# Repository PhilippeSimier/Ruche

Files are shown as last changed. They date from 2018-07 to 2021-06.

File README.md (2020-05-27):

# The connected Beehive 
D’une installation facile et rapide, le système se positionne sous n’importe quelle ruche et délivre en temps réel un suivi précis des grandeurs mesurées.  Si la connexion réseau est présente, les grandeurs mesurées sont stokées sur la plate forme Thing Speak,  dans le cas contraire, les mesures sont enregistrées localement dans une base de données. Les mesures peuvent être consultées via des vues graphiques sur un site WEB.

**ThingSpeak** est une API et une application open source pour l'« Internet des objets », permettant de stocker et de collecter les données des objets connectés en passant par le protocole HTTP via Internet. Les données collectées peuvent être analysées avec des programmes MATLAB. On peut ainsi tracer des diagrammes de corrélation, effectuer des statistiques (calcul de moyenne mini maxi etc...

En cas de besoin d’intervention, des alertes sont transmises par  sms sur  smartphone. Ce service est assurée par une API sur la Gateway.

## Câblage d'une balance connectée
Réaliser le câblage suivant sur la carte **snir-hat**
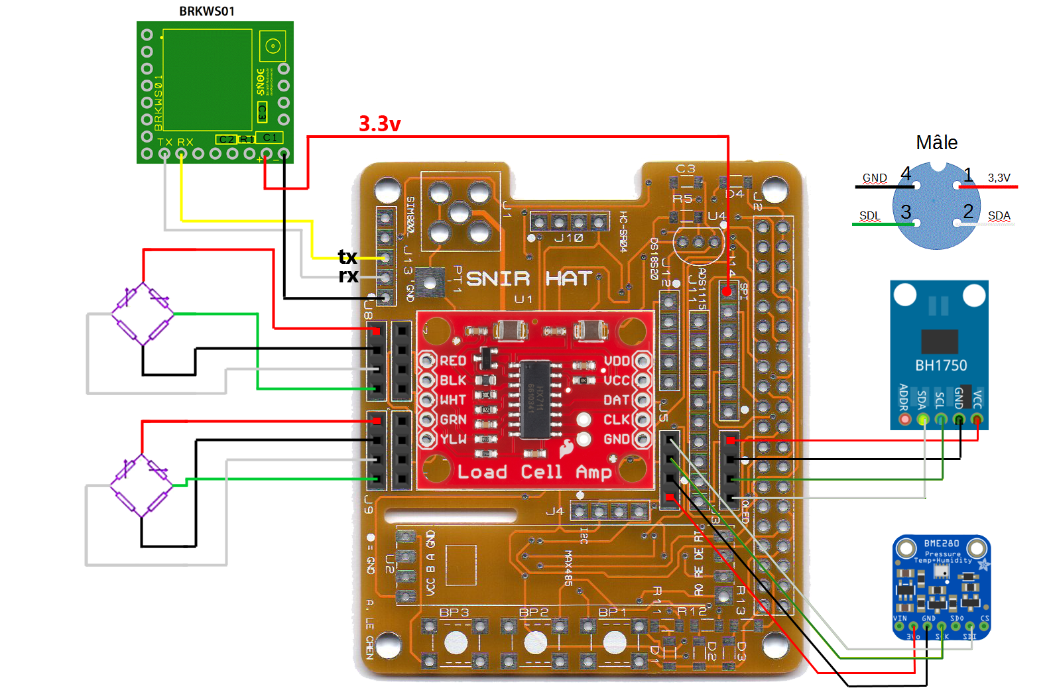
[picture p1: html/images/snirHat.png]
schema cablage HX711

 
## Prérequis Installation

Sous **raspbian lite Buster** Les paquets suivants doivent être installés 

 1. git
 2. apache2
 2. mariadb
 3. php
 4. php7.0-curl
 4. phpmyadmin
 5. libcurl4-openssl-dev
 6. libmysqlcppconn-dev

Configuration de Apache

 1. Activer le module cgi
 2. Activer le module rewrite
 2. ajouter www-data au groupe video et i2c
 
Vous pouvez utiliser le script shell **RaspbianOSsetup.sh** pour installer les packages requis et configurer Apache. 
```bash
~ $ sudo su
/home/pi# apt install git
/home/pi# git clone https://github.com/PhilippeSimier/Ruche.git
/home/pi# cd Ruche/
/home/pi/Ruche#  ./Raspbian_OS_Setup/RaspbianOSsetup.sh
```
## Création de la base de données data

 - création d'une base **data**
 - création d'un utilisateur **ruche** avec mdp **toto**
 - création des tables users, things, channels et feeds
 
Vous pouvez  en tant que **root** utiliser le script shell **mysql_data_setup** pour installer la base de données  et créer l'utilisateur 'ruche' requis.

```bash
/home/pi/Ruche# ./Raspbian_OS_Setup/mysql_Data_setup
```
 
## Compilation & installation 

 **make  all** 
```bash
~/Ruche $ cd Capteurs
~/Ruche/Capteurs $ make all
~/Ruche/Capteurs $ make install
~/Ruche/Capteurs $ make clean
```
Installation des exécutables

**make install**

Installation des fichiers de configurations

**make config**

## Thing Speak

Pour pouvoir télécharger les données sur ThingSpeak à des fins d'analyse et de traitement, vous devez créer un compte.

Une fois le compte créé, vous devez créer un nouveau canal en lui donnant un nom.
Les champs reflètent les données que vous allez télécharger.  
Vous devez définir les champs  comme sur la figure ci-dessous. 
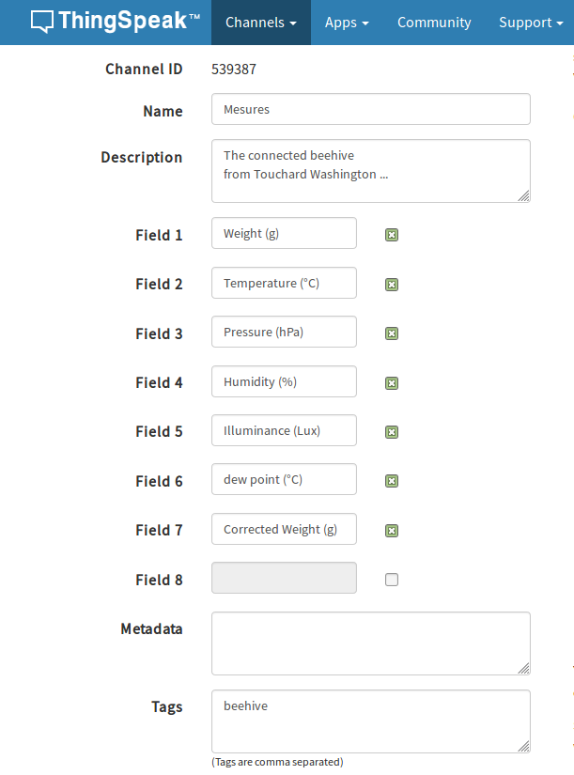
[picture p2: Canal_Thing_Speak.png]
Canaux Thing Speak


À l'issue de cette opération, cliquez sur Enregistrer le canal.  Vous êtes maintenant prêt à télécharger les données de la ruche vers son canal correspondant.

Recherchez la clé API correspondant à votre canal (Write API Key).
À chaque canal correspondra une clé API unique, destinée à garantir le téléchargement des données au bon emplacement.

Veuillez à mémoriser la clé API **Write API Key** . Vous l'utiliserez comme argument des tâches thingSpeak qui seront exécutées à interval régulier par le processus cron.

## Configuration **crontab**
ajouter les tâches planifiées suivantes :

 - Exécution de **bddLog** toutes les 30 minutes;
 - Exécution de **thingSpeak** toutes les 30 minutes;
 - Exécution de **synchronisation** toute les 4 heures lorsque l'aiguille des minutes est sur 5. 

```bash
/home/pi/Ruche# crontab -e

*/30 * * * * /opt/Ruche/bin/bddLog >> /var/log/Ruche/activity.log 2>&1
*/30 * * * * /opt/Ruche/bin/thingSpeakGET XXXXXXXXXXXXX | /opt/Ruche/bin/envoyerURL >> /var/log/Ruche/activity.log 2>&1
*/30 * * * * /opt/Ruche/bin/weather XXXXXXXXXXXX | /opt/Ruche/bin/envoyerURL >> /var/log/Ruche/activity.log 2>&1

```
## Configuration et Etalonnage de la **balance**

La balance doit être étalonnée. Cette procédure consiste à prendre un poids connu (p. ex. 5 kg) et d'établir la relation pour que la valeur affichée à l'écran corresponde à la valeur connue.
Le programme **etalonnage** permet de déterminer les paramètres de cette relation et de les enregistrer dans le fichier **configuration.ini**.
Pour ce faire, en mode console lancer le programme **etalonnage**
```bash
~/Ruche $ cd Capteurs/
~/Ruche/Capteurs $ ./etalonnage
Quelle est l'unité de mesure ? (g kg lb)
kg
Quelle est la précision d'affichage : 1 ou 2 chiffres après la virgule
2
Donnez le gain souhaité : 128 ou 64 ? 
64

```
Répondez aux différentes questions, le programme va ensuite lancer la procédure de tarage, puis va vous demandez de placer un poids étalon sur le plateau de la balance.  Vous devez donner sa valeur. Le programme continue alors sa procédure.

Sans retirer le poids étalon lancer le programme testBalance
```bash
~/Ruche/Capteurs $ ./testBalance
* 15.00
```
Vous devriez voir s'afficher sur l'écran la valeur du poids étalon.
La configuration de la balance est terminée.

## Test des capteurs BME280 et BH1750
Le test de fonctionnement du capteur BME280 peut être effectué en exécutant le programme : **testBME280**
```bash
~/Ruche/Capteurs $ ./testBME280 
Capteur BME 280 présent sur le bus I2C
 Température (C)  : 28.0 °C
 Température (F)  : 82.5 °F
 Pression         : 1018.9 hPa
 Humidité         : 42.3 %
 Pression P0      : 1023.7 hPa
 Point de rosée   : 14.0 °C

```
Le test de fonctionnement du capteur BH1750 peut être effectué en exécutant le programme : **testBH1750**

```bash
~/Ruche/Capteurs $ ./testBH1750
Capteur d'éclairement
Eclairement : 222.9 lx
Eclairement : 222.9 lx
Eclairement : 222.9 lx
^C
```

## Site Web

Dans un navigateur web ouvrir l'url suivante: 
http://adresse_IP_du_raspberry

--------

## Changelog

 **04/08/2018 :** Ajout du README . 
 **10/09/2018 :** Ajout du  script shell RaspbianOSsetup.sh
 
> **Notes :**

> - Licence : **licence publique générale** 
> - Auteur **Philippe SIMIER Lycée Touchard Le Mans**
>  
<!-- TOOLBOX 

Génération des badges : https://shields.io/
Génération de ce fichier : https://stackedit.io/editor#

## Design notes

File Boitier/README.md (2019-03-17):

# Boitier Ruche connectée

## Conception boîtier 3D

Le boitier se place sous la ruche. Il contient la batterie, le chargeur solaire, le raspberry pi. Le couvercle est le plateau de la balance. 

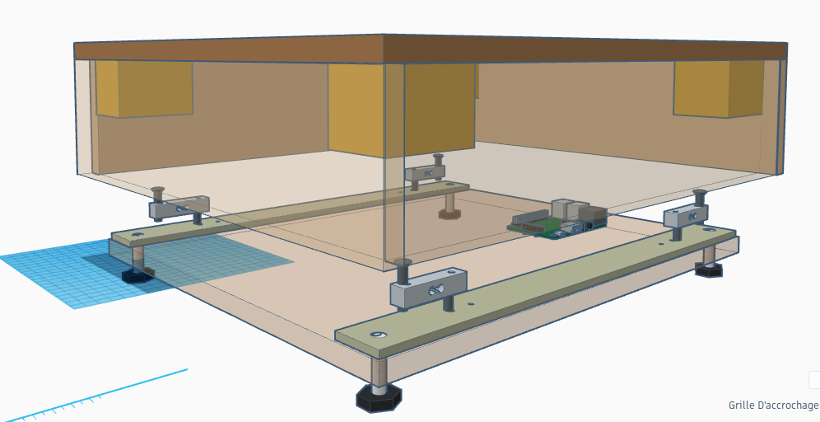
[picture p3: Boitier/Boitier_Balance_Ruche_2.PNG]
boitier


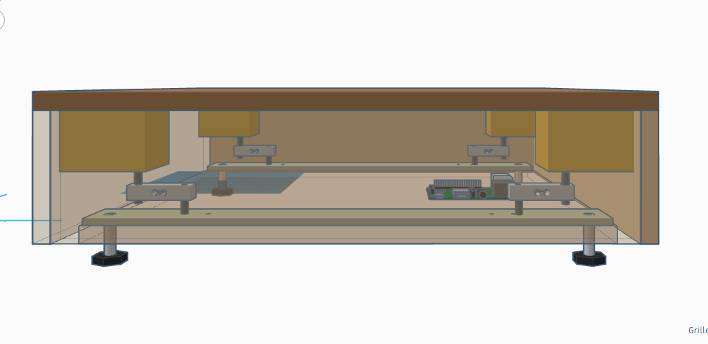
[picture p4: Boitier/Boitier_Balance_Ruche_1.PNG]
boitier


[Modèle 3D](https://www.tinkercad.com/things/l4oGmu31n0B-boitier-balance-ruche)

## Changelog

 **04/08/2018 :** Ajout du README . 
 **10/09/2018 :** Ajout du  script shell RaspbianOSsetup.sh
 
> **Notes :**

> - Licence : **licence publique générale** 
> - Auteur **Philippe SIMIER Lycée Touchard Le Mans**
>  
<!-- TOOLBOX 

Génération des badges : https://shields.io/
Génération de ce fichier : https://stackedit.io/editor#

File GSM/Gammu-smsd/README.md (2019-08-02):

# Gammu-smsd

**gammu-smsd** est un programme daemon qui se charge de recevoir et d'envoyer les SMS. Pour ce faire il analyse périodiquement le modem GSM pour lire les SMS reçus et les stocker dans un répertoire défini. Il envoie les SMS placés dans le répertoire des SMS à envoyer.

***Attention*** vous ne pouvez pas exécuter Gammu et Gammu-SMSD en même temps sur le même modem GSM, cependant vous pouvez contourner cette limitation en suspendant temporairement SMSD en utilisant les signaux SIGUSR1 et SIGUSR2.

 - **SIGUSR1** Suspend  SMSD, en fermant la connexion au modem GSM
 - **SIGUSR2** Reprend  SMSD (après la suspension précédente).

## Installation
```bash
pi@raspberrypi3:~ $ sudo apt-get install gammu-smsd
pi@raspberrypi3:~ $ gammu-smsd -v
Gammu-smsd version 1.33.0

```
## Configuration de Gammu-smsd

gammu-smsd lit la configuration à partir d'un fichier de configuration. Son emplacement peut être spécifié sur la ligne de commande (option -c), sinon le fichier par défaut **/etc/gammu-smsdrc** est utilisé.

La section **[gammu]** est la configuration d'une connexion au modem GSM
la section **[smsd]** configure le démon SMS lui-même.
Le paramètre **pin**  est facultatif, mais vous devez le définir si votre carte SIM après la mise sous tension nécessite un code PIN.

Exemple de fichier de configuration :
```
# Configuration file for Gammu SMS Daemon

[gammu]

port = /dev/ttyUSB0
connection = at
GammuLoc = fr_FR.UTF8
gammucoding = utf8

[smsd]
service = files
logfile = syslog
# Increase for debugging information
debuglevel = 0
RunOnReceive = /home/pi/Ruche/SMSDreceive.sh
pin = 0000

# Paths where messages are stored
inboxpath = /var/spool/gammu/inbox/
outboxpath = /var/spool/gammu/outbox/
sentsmspath = /var/spool/gammu/sent/
errorsmspath = /var/spool/gammu/error/
```
Le répertoire **/var/spool/gammu/inbox/** contient les SMS reçus. Chaque SMS reçu est mémorisé dans un fichier texte. Le nom du fichier est composé de la date de réception suivi du numéro de téléphone expéditeur.  Exemple : **IN20180929_220922_00_+33689744236_00.txt**

Le répertoire  /var/spool/gammu/sent/ contient les SMS émis. Chaque SMS émis est mémorisé dans un fichier texte.  Exemple :
**OUTC20180930_181847_00_0689744235_sms0.smsbackup**

## Démarrer le démon smsd

```bash
pi@raspberrypi3:/etc $ sudo service gammu-smsd start
```

## Stoper le démon smsd
```bash
pi@raspberrypi3:/etc $ sudo service gammu-smsd stop
```

## Redémarrer le démon smsd
```bash
pi@raspberrypi3:/etc $ sudo service gammu-smsd stop restart 
```

## Vérifier l'état du démon gammu_smsd
```bash
pi@raspberrypi3:~ $ sudo service gammu-smsd status
● gammu-smsd.service - LSB: Gammu SMS daemon
   Loaded: loaded (/etc/init.d/gammu-smsd)
   Active: active (exited) since dim. 2018-09-30 17:50:35 CEST; 8min ago

sept. 30 17:50:35 raspberrypi3 gammu-smsd[29650]: gammu-smsd not yet configured, please...).
sept. 30 17:50:35 raspberrypi3 systemd[1]: Started LSB: Gammu SMS daemon.
Hint: Some lines were ellipsized, use -l to show in full.

```

## Envoyer un SMS 

**gammu-smsd-inject** est un programme qui **met en file d'attente le message** , qui sera ensuite envoyé par le démon à l'aide du modem GSM connecté.

Injecter un **message texte** jusqu'à 160 caractères standard:
```bash
root@raspberrypi3:/# gammu-smsd-inject TEXT 0689744236 -text "Nous sommes le `date`"
gammu-smsd-inject[3314]: Created outbox message OUTC20180930_193115_00_0689744236_sms0.smsbackup
Written message with ID /var/spool/gammu/outbox/OUTC20180930_193115_00_0689744236_sms0.smsbackup

```
Injecter un **message texte Unicode**: 
```bash
root@raspberrypi3:/home/pi# gammu-smsd-inject TEXT 0689744236 -unicode -text "Zkouška sirén été Anaïs"
```

Injecter le contenu d'un **fichier text** :
Le contenu d'un fichier texte peut être envoyé sur l'entrée standard de gammu-smsd-inject. 
```bash
root@raspberrypi3:/home/pi/# cat textSMS | gammu-smsd-inject TEXT 0689744235 -unicode -len 400
```

## Recevoir un SMS et effectuer un traitement

Chaque fois que SMSD reçoit un message et le stocke dans le service backend, il peut lancer l'exécution de votre propre programme pour effectuer tout traitement sur le message reçu.

Exemple  de script: 
pi@raspberrypi3:~# nano /home/pi/Ruche/SMSDreceive.sh
```bash
#!/bin/sh
# script exécuter par le démon Gammu lors de la reception d'un SMS
# variables d'environnement
# SMS_1_CLASS
# SMS_1_NUMBER= numero tel
# SMS_1_TEXT= message
# SMS_MESSAGES = le nbre de SMS reçus
# en argument le fichier contenant le SMS

echo "---------------------------------------" >> /home/pi/Ruche/sms.log
echo "$(date) : $SMS_MESSAGES  SMS(s) recu(s)" >> /home/pi/Ruche/sms.log
echo "from : $SMS_1_NUMBER" >> /home/pi/Ruche/sms.log
echo "message : $SMS_1_TEXT" >> /home/pi/Ruche/sms.log
echo "fichier contenant le SMS : $1" >> /home/pi/Ruche/sms.log

curl --request GET  --url $SMS_1_TEXT  --header 'cache-control: no-cache' >> /home/pi/Ruche/sms.log 2>&1

exit 0

```
**Attention** Le script doit être exécutable par **gammu**,  il doit donc être exécutable, +x,  il doit avoir pour propriétaire gammu et appartenir au groupe gammu.
Ne pas oublier d'ouvrir les droits en écriture pour de répertoire Ruche.
```bash
pi@raspberrypi3:~/Ruche $ chmod +x SMSDreceive.sh
pi@raspberrypi3:~/Ruche $ sudo chown gammu SMSDreceive.sh
pi@raspberrypi3:~/Ruche $ sudo chgrp gammu SMSDreceive.sh
pi@raspberrypi3:~/Ruche $ ls -l
total 4
-rwxr-xr-x 1 gammu gammu 578 oct.   6 11:10 SMSDreceive.sh
pi@raspberrypi3:~ $ cd ..
pi@raspberrypi3:~ $ chmod 777 Ruche/

```

[Plus d'infos sur le site officiel GAMMU](https://wammu.eu/docs/manual/smsd/run.html)

## Envoyer un SMS depuis un script php

```php
<?php

    $ligne  = "gammu-smsd-inject TEXT 0612345678 -text \"Test de l'envoi SMS avec API\"";
    $output = shell_exec($ligne);
    echo "<p>output : </p><pre>" . $output . "</pr>";
?>
```
L’utilisateur apache (www-data) doit avoir accès à  /dev/ttyUSB0
Pour ce faire ajouter **www-data** au groupe **dialout**
```bash
    sudo usermod -a -G dialout www-data
```
www-data doit pouvoir exécuter gammu-smsd-inject avec les droits du propriétaire  :    *chmod +s*
```bash
root@raspberrypi3:/# cd /usr/bin/
root@raspberrypi3:/usr/bin# chmod +s gammu-smsd-inject
root@raspberrypi3:/usr/bin# chmod +s gammu-smsd-monitor

``` 

## Obtenir le niveau du signal

```bash
pi@raspberrypi3:~ $ sudo gammu-smsd-monitor -n 1 -d 1 | grep NetworkSignal
NetworkSignal: 60
```

## Obtenir l'IMEI
L'imei est un numéro permettant d'identifier de manière unique un modem GSM.
```bash
pi@PI1003:~ $ sudo gammu-smsd-monitor -n 1 -d 1 | grep IMEI
IMEI: 863071014745125

```

## Modem GSM non reconnu

Des problèmes d'émissions et de réceptions de messages ont été constatés. Après recherche et étude des logs, il s'est avéré que Gammu  avait perdu la connexion avec le modem gsm. le point de montage USB de notre modem **/dev/ttyUSB0** n'existait plus.
Le problème est que Linux fait varier ce point de montage à chaque démarrage et redémarrage même si le port USB où le modem est connecté reste inchangé. Le point de montage peut alors avoir la valeur « ttyUSB1 », « ttyUSB2 », « ttyUSB3 »....
Pour résoudre ce problème, une règle de montage des périphériques USB a été ajoutée au gestionnaire de périphérique « udev » qui est présent dans le noyau Linux dont dispose Raspbian.

Nous devons fixer le chemin afin qu'il ne change pas si d'autres périphériques sont connectés, nous choisissons **e169**. Il faut bien comprendre que nous allons ajouter un second chemin fixe en plus du premier qui lui restera dynamique, nous ne le remplaçons pas.

Première étape : Récupérez l'ID avec :  **lsusb | grep -i huawei**
 
```bash
root@raspberrypi3:/etc/udev# lsusb | grep -i huawei
Bus 001 Device 005: ID 12d1:1001 Huawei Technologies Co., Ltd. E169/E620/E800 HSDPA Modem

```
Les 2 champs qui nous intéressent sont ceux après "ID" :

 - **12d1 = idVendor**
 - **1001 = idProduct**

**Deuxième étape Fixons le chemin :**
```bash
root@raspberrypi3:~# cd /etc/udev/rules.d/
root@raspberrypi3:/etc/udev/rules.d# nano usb-modem.rules 
```
Ajouter la règle suivante dans le fichier:

la règle est faite d'un ensemble de clefs de correspondances et de clefs d'assignation, séparées par des virgules. Les clefs de correspondances sont les conditions utilisées pour identifier le périphérique sur lequel la règle agit. Quand toute la série de ces clefs de correspondance correspond bien au périphérique, alors la règle est appliquée et les actions des clefs d'assignation sont appliquées.
```
KERNEL=="ttyUSB*",ATTRS{idVendor}=="12d1",ATTRS{idProduct}=="1001",SYMLINK+="e169"
```
Cette ligne indique au système que l'appareil correspondant au idVendor et idProduct du modem monté sur n'importe quel ttyUSB devra être accessible sous le nom e169. Ainsi, le modem gsm sera toujours monté dans le répertoire /dev/e169, réglant ainsi toutes nos erreurs de déconnexions.

**Troisième étape : Vérification** 

```
root@raspberrypi3:/home/pi# ls -l /dev/e*
lrwxrwxrwx 1 root root 7 juil. 30 12:55 /dev/e169 -> ttyUSB0

```
**Quatrième étape : Modification du fichiers de configuration /etc/gammu-smsdrc** 

```
[gammu]

port = /dev/e169
connection = at
....

```

## Changelog

 **30/09/2018 :** Ajout du README .
 **30/07/2019 :** Ajout résolution de la déconnexion du modem  

> **Notes :**

> - Licence : **licence publique générale** 
> - Auteur **Philippe SIMIER Lycée Touchard Le Mans**
>  
<!-- TOOLBOX 

Génération des badges : https://shields.io/
Génération de ce fichier : https://stackedit.io/editor#

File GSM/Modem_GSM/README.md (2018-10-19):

# Modem GSM

Pour émettre des sms, la Raspberry Pi doit pouvoir se connecter au réseau GSM d'un opérateur. Pour ce faire, nous utilisons un modem GSM et une carte SIM avec un abonnement comprenant des appels limités à 2h mais permettant l'envoi de sms et de mms illimités. La plupart des opérateurs proposent des forfaits de ce genre pour 2€ par mois.

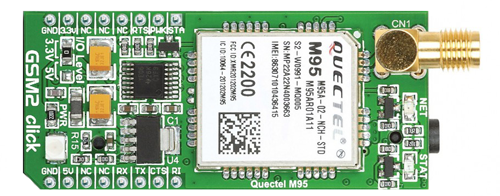
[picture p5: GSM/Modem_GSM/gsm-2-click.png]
Modem GSM


 L'activité sur le réseau est indiquée par la LED rouge NET, avec la signification suivante:
 - Continuellement éteint : l'appareil n'est pas alimenté.
 - Cycliquement un flash toutes les 800ms: **Recherche réseau / ou code pin non enregistré**.
 - Cycliquement un flash toutes les 2s: **enregistré sur le réseau**
 - Hautement cyclique un flash toutes les 600ms: **transfert de données GPRS est en cours**

Une LED jaune appelée STAT est utilisée pour indiquer l'état de l'appareil. Lorsqu'elle est allumée, l'appareil est opérationnel. Elle signale également que l'initialisation du module interne est terminée et que le module est prêt à fonctionner.

La connexion au Raspberry se fait par l'intermédiaire d'un adaptateur USB. L'adaptateur fournit l'interface nécessaire à la connexion série via une connexion USB.

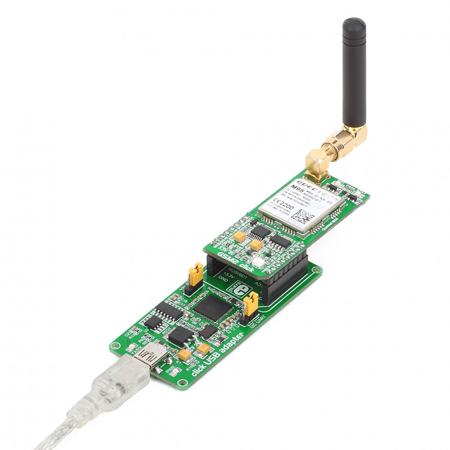
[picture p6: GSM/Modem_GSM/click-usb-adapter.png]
adaptateur USB


## Test & Installation
Avant de connecter le modem GSM exécuter **lsusb** 
```bash
pi@PI1003:~ $ lsusb
Bus 001 Device 003: ID 0424:ec00 Standard Microsystems Corp. SMSC9512/9514 Fast Ethernet Adapter
Bus 001 Device 002: ID 0424:9512 Standard Microsystems Corp. LAN9500 Ethernet 10/100 Adapter / SMSC9512/9514 Hub
Bus 001 Device 001: ID 1d6b:0002 Linux Foundation 2.0 root hub
```
Connecter le modem sur la prise USB puis relancer la commande **lsusb**
```bash
pi@PI1003:~ $ lsusb
Bus 001 Device 004: ID 0403:6010 Future Technology Devices International, Ltd FT2232C Dual USB-UART/FIFO IC
Bus 001 Device 003: ID 0424:ec00 Standard Microsystems Corp. SMSC9512/9514 Fast Ethernet Adapter
Bus 001 Device 002: ID 0424:9512 Standard Microsystems Corp. LAN9500 Ethernet 10/100 Adapter / SMSC9512/9514 Hub
Bus 001 Device 001: ID 1d6b:0002 Linux Foundation 2.0 root hub
```
Un composant supplémentaire doit apparaître: 
**Device 004: ID 0403:6010**

Lister les devices ttyUSB
```bash
pi@PI1003:~ $ ls /dev/ttyUSB*
/dev/ttyUSB0  /dev/ttyUSB1
```

## Installation de minicom
**Minicom** est un programme de contrôle de modem.

ligne de commande pour installer :
```bash
pi@PI1003:~ $ sudo apt-get install minicom
```
## Configuration de minicom

```bash
pi@PI1003:~ $ sudo minicom -s
```
Une fenêtre de configuration apparaît pour configurer les paramètres de la communication.
```bash
            +-----[configuration]------+
            | Filenames and paths      |
            | File transfer protocols  |
            | Serial port setup        |
            | Modem and dialing        |
            | Screen and keyboard      |
            | Save setup as dfl        |
            | Save setup as..          |
            | Exit                     |
            | Exit from Minicom        |
            +--------------------------+
```
Sélectionner **Serial port setup** avec les flèches bas et haut du clavier
```bash
    +-------------------------------------------------------------+
    | A -    Serial Device      : /dev/ttyUSB0                    |
    | B - Lockfile Location     : /var/lock                       |
    | C -   Callin Program      :                                 |
    | D -  Callout Program      :                                 |
    | E -    Bps/Par/Bits       : 115200 8N1                      |
    | F - Hardware Flow Control : No                              |
    | G - Software Flow Control : No                              |
    |                                                             |
    |    Change which setting?                                    |
    +-------------------------------------------------------------+
            | Screen and keyboard      |
            | Save setup as dfl        |
            | Save setup as..          |
            | Exit                     |
            | Exit from Minicom        |
            +--------------------------+
```
Sélectionner **Bps/Par/Bits** en appuyant sur la touche E, pour régler la vitesse de transmission sur **115200** bauds, **8**bits par caractère, **pas de parité**, **un bit de stop**.  
Configurer l'option **Hardware Flow Control**  sur **No** et **Software Flow Control**  sur **No**

Ensuite sélectionner **Screen and keyboard**

              +-----------------[Screen and keyboard]-----------------+
              | A - Command key is         : ^A                       |
              | B - Backspace key sends    : BS                       |
              | C - Status line is         : enabled                  |
              | D - Alarm sound            : Yes                      |
              | E - Foreground Color (menu): WHITE                    |
              | F - Background Color (menu): BLACK                    |
              | G - Foreground Color (term): WHITE                    |
            +-| H - Background Color (term): BLACK                    |
            | | I - Foreground Color (stat): WHITE                    |
            | | J - Background Color (stat): BLACK                    |
            | | K - History Buffer Size    : 2000                     |
            | | L - Macros file            : .macros                  |
            | | M - Edit Macros                                       |
            | | N - Macros enabled         : Yes                      |
            | | O - Character conversion   :                          |
            | | P - Add linefeed           : No                       |
            | | Q - Local echo             : No                       |
            +-| R - Line Wrap              : No                       |
              | S - Hex Display            : No                       |
              | T - Add carriage return    : No                       |
              |  Change which setting?  (Esc to exit)                 |
              +-------------------------------------------------------+
Dans ce menu vous devez définir un echo local sur No (le modem GSM retourne un echo des caratères reçus).

Sortir du mode de configuration avec **"Save setup as dfl"**
Cela va enregistrer la configuration dans un fichier: /etc/minicom/minirc.dfl 

## Quitter minicom
Pour quitter minicom taper au clavier

 - Ctrl A
 - Z   (pour obtenir l'aide)
 - Q  (pour quitter)

## Exécuter minicom
```
pi@PI1003:~ $ sudo minicom -D /dev/ttyUSB0

Welcome to minicom 2.7

OPTIONS: I18n 
Compiled on May  7 2017, 05:18:49.
Port /dev/ttyUSB0, 10:58:00

Press CTRL-A Z for help on special keys

```
envoyer AT
le modem doit répondre OK

## Envoyer un SMS

A Chaque remise mise sous tension du modem le code pin doit être entré. Pour ce faire saisir la commande at suivante si le code pin est 0000:
```
AT+CPIN=0000
+CPIN: READY

OK

Call Ready
```
le modem répond **OK** puis un instant plus tard **Call Ready**

Passage en mode texte 
```
AT+CMGF=1
OK
```
Envoyer un message SMS saisir la commande AT+CMGS="0689744200" puis enter
le modem répond en affichant le prompt > saisir le message enter pour passer à la ligne, puis ctrl Z  pour envoyer. (Ctrl+Z, 0x1A, 26). Le modem répond alors =CMGS: 252 puis OK.
```
AT+CMGS="0689744236"
> mon premier message SMS avec le modem GSM
>                                            
+CMGS: 252
                                                                                                         
OK
```
Si vous obtenez la réponse erreur suivante,  
```
+CME ERROR: 11
```
le code pin est requis (SIM PIN required)

## Tableau des codes erreurs carte SIM 
| Erreur  | Description |
|---|---|
|CME ERROR: 10	| SIM not inserted |
|CME ERROR: 11	| 	SIM PIN required |
|CME ERROR: 12	| 	SIM PUK required |
|CME ERROR: 13	| 	SIM failure |
|CME ERROR: 14	| 	SIM busy |
|CME ERROR: 15	| 	SIM wrong |
|CME ERROR: 16	| 	Incorrect password |
|CME ERROR: 17	| 	SIM PIN2 required |
|CME ERROR: 18	| 	SIM PUK2 required |

 [gsm error](http://www.micromedia-int.com/fr/gsm-2/669-cme-error-gsm-equipment-related-errors)

--------

## Changelog

 **04/08/2018 :** Ajout du README . 
 **27/09/2018 :** Ajout du  README.md
 
> **Notes :**

> - Licence : **licence publique générale** 
> - Auteur **Philippe SIMIER Lycée Touchard Le Mans**
>  
<!-- TOOLBOX 

Génération des badges : https://shields.io/
Génération de ce fichier : https://stackedit.io/editor#

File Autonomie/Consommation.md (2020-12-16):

#  Limiter la consommation du Raspberry PI

Limiter la consommation d’un Raspberry pi en gardant un niveau de performance acceptable pour l’utilisation sur batterie avec panneau solaire.

##  Désactiver la carte son embarquée:

Vérifier la présence de la carte son avec la commande **aplay -l**

    root@oize:/etc/modprobe.d# aplay -l
    **** Liste des Périphériques Matériels PLAYBACK ****
    carte 0: Headphones [bcm2835 Headphones], périphérique 0: bcm2835 Headphones [bcm2835 Headphones]
      Sous-périphériques: 8/8
      Sous-périphérique #0: subdevice #0
      Sous-périphérique #1: subdevice #1
      Sous-périphérique #2: subdevice #2
      Sous-périphérique #3: subdevice #3
      Sous-périphérique #4: subdevice #4
      Sous-périphérique #5: subdevice #5
      Sous-périphérique #6: subdevice #6
      Sous-périphérique #7: subdevice #7
      
Créez un fichier **alsa-blacklist.conf** à l'aide de nano et enregistrez-le dans /etc/modprobe.d

    sudo nano /etc/modprobe.d/alsa-blacklist.conf

Ajouter la ligne suivante :

    blacklist snd_bcm2835
Redémarrer **reboot**
Vérifier l'absence de la prise en compte

    root@oize:/home/pi# aplay -l
    aplay: device_list:272: aucune carte son n'a été trouvée...

## Faire fonctionner le raspberry à une cadence un peu moins élevée:

Raspbian fixe la fréquence du processeur à 700 MHz par défaut.  Il ne serait pas raisonnable de conserver la fréquence maximale du processeur pour l'utilisation qui ne nécessite pas à tout moment la pleine puissance du processeur.

Le fichier **/boot/config.txt** est lu par le GPU pour la configuration matérielle avant que le CPU ne soit activé. 
Cela inclut le réglage de la fréquence  du cpu .  
Editer le fichier **config.txt**

    sudo nano  /boot/config.txt
Ajouter les lignes suivantes :

    force_turbo=0
    arm_freq=700
    arm_freq_min=100
**force_turbo = 0**  signifie «activer la mise à l'échelle de la fréquence du processeur»
  **arm_freq_min = 100**  Définit la fréquence cpu la plus basse. Par défaut, elle est de 700. 

## Désactiver la sortie HDMI:

**tvservice -o** désactive tout le pipeline d'affichage, y compris les horloges, le matériel vidéo Scaler, Pixel Valve, récupère les couches d'affichage de sdram, etc. il devrait être constaté une réduction de 17 mA du courant d'alimentation.

    sudo nano /etc/rc.local
Ajouter la ligne suivante :

    /opt/vc/bin/tvservice -o

## Activer la gestion de l’énergie à la demande:

Le noyau Linux a un pilote qui gère la politique de fréquence du processeur.  L'option suivante est disponible pour cela.

 - **performances** - utilise toujours la fréquence maximale du processeur  
 - **powersave** - utilise toujours la fréquence mini du processeur
 - **ondemand** - change la fréquence du processeur en fonction de la charge du processeur (sur rasbian, commute juste le min et le max)
 - **conservative** - change en douceur la fréquence du processeur en fonction de la charge du processeur

 Rasbian a défini **powersave** par défaut.

Mettez la commande dans /etc/rc.local.  L'exécution de la commande a lieu après le démarrage du noyau. Donc, cela ralentit le démarrage.

    sudo nano /etc/rc.local
Ajouter la ligne suivante

    cpufreq-set -g conservative
Connaitre la fréquence du CPU

    vcgencmd measure_clock arm
    
vsgencmd est un utilitaire de ligne de commande qui peut obtenir diverses informations du GPU VideoCore sur le Raspberry Pi. La plupart des informations disponibles ne sont utiles qu'aux ingénieurs de Raspberry Pi, mais il existe un certain nombre d'options très utiles disponibles pour les utilisateurs finaux.

## Changelog

 **15/12/2020 :** Ajout choix du panneau solaire photovoltaïque
 
> **Notes :**

> - Licence : **licence publique générale** 
> - Auteur **Philippe SIMIER Lycée Touchard Le Mans**
>  
<!-- TOOLBOX 

Génération des badges : https://shields.io/
Génération de ce fichier : https://stackedit.io/app#

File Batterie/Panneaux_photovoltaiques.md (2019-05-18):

# panneaux solaires photovoltaïques

Le panneau solaire alimente la raspberry et charge la batterie de manière à ce qu'il ait assez d'énergie pour fonctionner pendant la période nocturne. Étant donné que la ruche connectée passe environ la moitié de son temps «dans le noir», elle doit s’appuyer sur l’énergie stockée dans la batterie embarquée pour fonctionner.

La capacité d'une batterie à stocker de l'énergie et à fournir cette énergie au fil du temps est mesurée en terme de capacité de stockage de la batterie.  Cette grandeur se mesure  en coulomb ou ampères-heures.  Le programme coulombCounter surveille en permanence la quantité de courant circulant dans la batterie. 

## Conversion de l’énergie solaire

La lumière est composée de photons, porteurs d’énergie, pouvant extraire des charges électriques des matériaux semi-conducteurs tels que le silicium. Ainsi les panneaux solaires  produisent du courant électrique quand ils sont exposés à la lumière, par cette conversion photovoltaïque.

## Les différentes technologies   
 
### Panneaux solaires au silicium cristallin 
Le matériau photovoltaïque le plus couramment utilisé aujourd’hui est le **silicium cristallin, mono ou polycristallin**, à cause de sa grande disponibilité sur terre (dans le sable), sa bonne qualité électronique et donc son bon rendement de conversion au soleil. Le rendement énergétique des panneaux solaires à base polycristalline est généralement de 13 à 16%.

### Panneaux solaires au silicium amorphe

Le silicium amorphe quant à lui, présente des avantages spécifiques :

 - Réponse à **faible éclairement et sous ensoleillement diffus** ( par temps couvert de 20 à 3 000 lux)
 - Facilité de mise en oeuvre sur de petits formats, à toutes les tensions
 - Quasi insensibilité à la hausse de température au soleil

### Caractérisques

Le Watt crête (Wc) est la puissance nominale que délivre un panneau photovoltaïque dans les conditions optimales c'est à dire : une puissance d’ensoleillement de 1 000 W/m2, les rayons perpendiculaires au capteur, la température des cellules à 25° C.

## Choix
On suppose que la puissance d’un panneau solaire est proportionnelle à l’éclairement, même lorsqu’il est faible. Ce qui est loin d’être le cas pour toutes les technologies ! Le silicium cristallin voit sa tension en particulier baisser fortement quand l’éclairement baisse et il ne peut guère produire en dessous de 100 W/m² (10 000 lux). 

Le silicium amorphe, quant à lui, possède un moindre rendement au soleil, mais il est adapté à tous les éclairements. Or dans le cas d'un ciel nuageux, l’éclairement ne dépasse pas les 1000-3000 lux. Le **silicium amorphe** est donc bien souvent le meilleur choix pour produire tout au long de l’année, par tous les temps. 

## Composition

Le système photovoltaïque autonome comprend :

 - un (ou plusieurs) panneaux solaire(s) photovoltaïque(s) au silicium
 - un régulateur de charge 
 - une batterie  LiFePO4 selon la capacité requise et la durée de vie
 - des composants de conversion DC/DC  (12V/5V)

Le but du régulateur est avant tout de protéger la batterie contre les effets de surcharge et de décharge profonde.

## Changelog

 **08/05/2019 :** Ajout choix du panneau solaire photovoltaïque
 
> **Notes :**

> - Licence : **licence publique générale** 
> - Auteur **Philippe SIMIER Lycée Touchard Le Mans**
>  
<!-- TOOLBOX 

Génération des badges : https://shields.io/
Génération de ce fichier : https://stackedit.io/editor#

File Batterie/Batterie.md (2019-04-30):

# Batterie

## Choix
  En 1996, une nouvelle technologie a fait son apparition : Le Lithium Fer Phosphate (Connu sous LifePo4 ou LFP) et ses dérivés. Ces batteries ont une densité d’énergie légèrement plus faible que les NMC mais sont intrinsèquement non combustibles, et donc extrêmement sécurisées.
  
  Le tableau ci-dessous vous donne un élément de comparaison entre une batterie: **Plomb**, **Nickel**, **Lithium**  NMC (Lithium Nickel Manganèse Cobalt) et **LFP** (Lithium Fer Phosphate). 
  
  | type                    |  Plomb   | Nickel NiMH |  LiFePO4   |     NMC    |
  |-------------------------|----------|-------------|------------|------------|
  | tension   V             |   12     |     12      |    12.8    |  14.4      |
  | Energie Massique        | 40 Wh/kg |  90 Wh/kg   | 110 Wh/kg  |  170 Wh/Kg | 
  | Durée de vie à 100% DOD |   300    |     500     |    500     |  800       |
  | Durée de vie à 80% DOD  |   600    |     700     |    3000    |   2000     | 
  | Profondeur décharge     |   50%    |      80%    |    90%     |  90%       |
  | Rendement à C           |	  60%    |     66%     |    95%     |  95%       |
  |	Indice de prix          |   23€    |     107€    |    110€    |  100€      |
  | Temps de charge         |   8h     |     2h      |     1h     |   2h       |

Les principaux avantages des batteries LiFePO4 sont : un gain de poids, une durée de vie augmentée sans entretien, des cycles de recharge et de décharge rapide avec un excellent rendement énergétique.

Contrairement aux batteries Plomb, les batteries Lithium peuvent être déchargées quasi totalement (de 90% à 100%) sans se dégrader.  En considérant une batterie de 100Ah, si une batterie au Plomb a une capacité utile comprise entre 30 à 50Ah, la batterie Lithium pourra fournir jusqu’à 100 Ah.

A la différence des batteries au plomb ou au Nickel, les batteries Lithium ne se dégradent pas si elles ne sont pas régulièrement chargées à 100% et le processus de charge est plus rapide que pour le plomb. Pour les applications solaires, une longue période pluvieuse empêchant la charge totale n’affectera pas la durée de vie de la batterie.

Les batteries au Plomb sont moins efficaces pour stocker l’énergie que le Lithim-Ion. La charge des batteries Lithium a un rendement proche de 95% alors que le plomb avoisine 60%. Ceci est particulièrement important pour les applications solaires où l’on cherche à capter et stocker le maximum d’énergie des panneaux solaires. 40% d’énergie captée est perdue lorsqu’elle est stockée dans une batterie au plomb.

## 2 Unité de charge

le coulomb  est défini comme un ampère pendant une seconde :

    1A x 1s = 1C

Puisqu'il y a 3600 secondes dans une heure, un ampère-heure équivaut à 3600 coulombs:

    1Ah = 3600C

## 2 Détermination du SOC

Il existe plusieurs manières pour mesurer l’état de charge (SoC) ou la profondeur de décharge (DoD) d’une batterie. 

#### 2-1 Mesure d’état de charge (SoC) par méthode OCV (Open Circuit Voltage)

Tous les types de batteries ont un point commun : la tension à leurs bornes diminue ou augmente en fonction de leur niveau de charge. La tension sera maximale lorsque la batterie est totalement chargée et minimale lorsqu’elle est vide. 
Cette relation entre tension et SOC dépend directement de la technologie de batterie utilisée.
le schéma ci dessous montre la courbe de décharge pour une batterie au plomb de 7Ah 12V
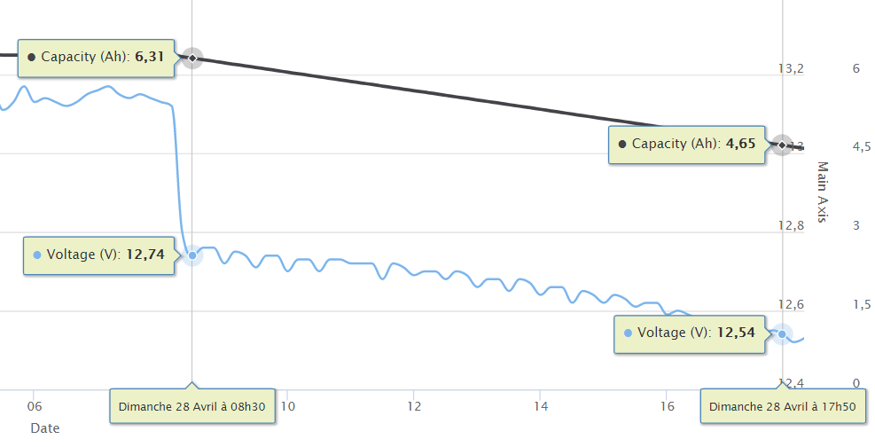
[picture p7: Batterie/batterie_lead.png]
courbe batterie lead

On peut constater que la batterie au plomb a une courbe relativement linéaire, ce qui permet une bonne estimation de l’état de charge connaissant la tension en circuit ouvert.
C'est le moyen utilisé par la méthode **obtenirSOC** de la classe **ina219**.
```cpp
 float ina219::obtenirSOC()
```
 
#### 2-2 2 Mesure d’état de charge (SoC) par compteur de Coulomb

le SOC est le rapport entre la charge et la capacité nominale exprimé en %.

Pour suivre l’état de charge lors de l’utilisation de la batterie, la méthode la plus intuitive consiste à suivre le courant en l’intégrant durant l’utilisation. Cette intégration donne de manière directe la quantité de charges électriques injectées ou soutirées à la batterie permettant ainsi de quantifier précisément le SoC de la batterie.

Contrairement à la méthode OCV, cette méthode est en mesure de déterminer l’évolution de l’état de charge pendant l’utilisation de la batterie. Elle ne nécessite pas que la batterie soit au repos pour effectuer une mesure précise.

C'est la méthode utilisée par le programme **/Capteurs/battery.cpp**
Pour garder une trace de la charge, le dernier état de charge calculé  est enregistré dans le fichier **battery.ini**

Bien que la mesure du courant soit effectuée par une résistance de précision 0.1 Ohm, de faibles erreurs de mesures interviennent, liées à la fréquence échantillonnage de la mesure. Pour corriger ces petites erreurs, le compteur de Coulomb est repositionné automatiquement à chaque cycle de charge. L'algorithme s’appuie alors sur la mesure de la tension de la batterie en état de veille, puis fait une correction en se basant sur la relation entre la tension de circuit ouvert (open cell voltage) de la batterie et l’état de charge de la batterie.

## Changelog

 **28/04/2019 :** Ajout choix de la batterie
 
> **Notes :**

> - Licence : **licence publique générale** 
> - Auteur **Philippe SIMIER Lycée Touchard Le Mans**
>  
<!-- TOOLBOX 

Génération des badges : https://shields.io/
Génération de ce fichier : https://stackedit.io/editor#

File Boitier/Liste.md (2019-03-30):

# Liste des pièces à commander

## Raspberry  & Capteurs
 | Qte    | Désignation         | Référence  | Prix |
 |--------|---------------------|------------|------|
 | 1  | Carte Raspberry Pi3 B+ | 35790 | 43,95 € |
 | 4  | Capteur de force 50 kg CZL635-50 | 25558 | 38,00 € |
 | 1  | Amplificateur pour capteur de force HX711 | 34732 | 10,80 € |
 | 1  | Capteur de t°, d'humidité et de pression BME 280 | 34076 | 22,90 € |
 | 1 | Capteur de courant INA219B | 32322 | 11,90 € |
 | 1 | Capteur de lumière BH1750  | 31748 | 16,35 € | 

## Boitier Visserie Entretoises
 | Qte    | Désignation         | Référence  | Prix |
 |--------|---------------------|------------|------|
 | 2 |   Jeu de 4 entretoises M/F 11mm BMF11 |  11572 | 2,80 € |
 | 2 |  10 écrous acier M2,5 |  11613 | 0,30 € |
 | 1 | 10 vis acier M2,5 6mm |  11610 | 0,25 € |
 | 1 | Boîtier ABS étanche G340M | 11906 | 12,90 € |
 | 2 | Presse-étoupe PG9 | 11341 | 1,60 € |
 | 1 | 10 vis auto-taraudeuses 2,2x6,5mm | 11850 | 0,30 € |
 | 1 | 10 vis auto-taraudeuses 2,9x6,5mm | 11853 | 0,30 € |
 | 3 | Gaine tressée FLEX05 | 08815 | 2,10 € |

## Connecteur
 | Qte    | Désignation         | Référence  | Prix |
 |--------|---------------------|------------|------|
 | 3 | Femelle 4 broches  | 08581 | 4,80 € |
 | 3 | Embase chassis mâle 4 broches | 08585 | 4,80 € |

## Changelog

 **30/03/2019 :** Ajout Liste de pièces
 
> **Notes :**

> - Licence : **licence publique générale** 
> - Auteur **Philippe SIMIER Lycée Touchard Le Mans**
>  
<!-- TOOLBOX 

Génération des badges : https://shields.io/
Génération de ce fichier : https://stackedit.io/editor#

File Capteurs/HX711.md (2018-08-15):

# Amplificateur convertisseur HX711

# Description

le module HX711 est un amplificateur pour capteurs de force à pont de Wheatstone associé à un convertisseur analogique-numérique. Les données  sont transmises sur un bus SPI de type propriétaire qui utilise une ligne d'horloge (SCK) et de données (DOUT).  Le nombre d'impulsions d'horloge permet de configurer le gain de l'amplificateur. 

 - 25 impulsions gain = 128 Canal = A (tension d'entrée différentielle +- 20mV)
 - 26 impulsions gain =  32 Canal = B (+- 80mV)
 - 27 impulsions gain =  64 Canal = A (+- 40mV)

le driver **SPI** (Serial Peripheral Interface) du noyau linux permet seulement de créer des impulsions d'horloge par multiple de 8, pour contourner cette limitation l'idée originale consiste à utiliser la ligne de données MOSI du bus SPI pour générer les 25 impulsions d'horloge. En écrivant la valeur **10101010** (0xaa en hexadécimal), nous obtenons 4 impulsions. Il suffit donc d'envoyer 6 fois cette valeur pour obtenir 24 impulsions, puis d'écrire la valeur 0x80 pour obtenir la 25 éme impulsions.
 
# Câblage
La plupart des cellules de pesage disposent de quatre « jauges de contrainte » pour mesurer la force exercée par l'objet pesé.
La tendance actuelle est aux jauges à trame, dites aussi jauges imprimées. Elles sont obtenues à partir d'une lame, formée d'une feuille mince (quelques micromètres) d'un alliage métallique et d'un support isolant (résine synthétique). À mesure que le flexible ploie, les jauges de contrainte se déforment, ce qui modifie le courant électrique qui les traverse. Cette modification est proportionnelle au poids de l'objet pesé. 

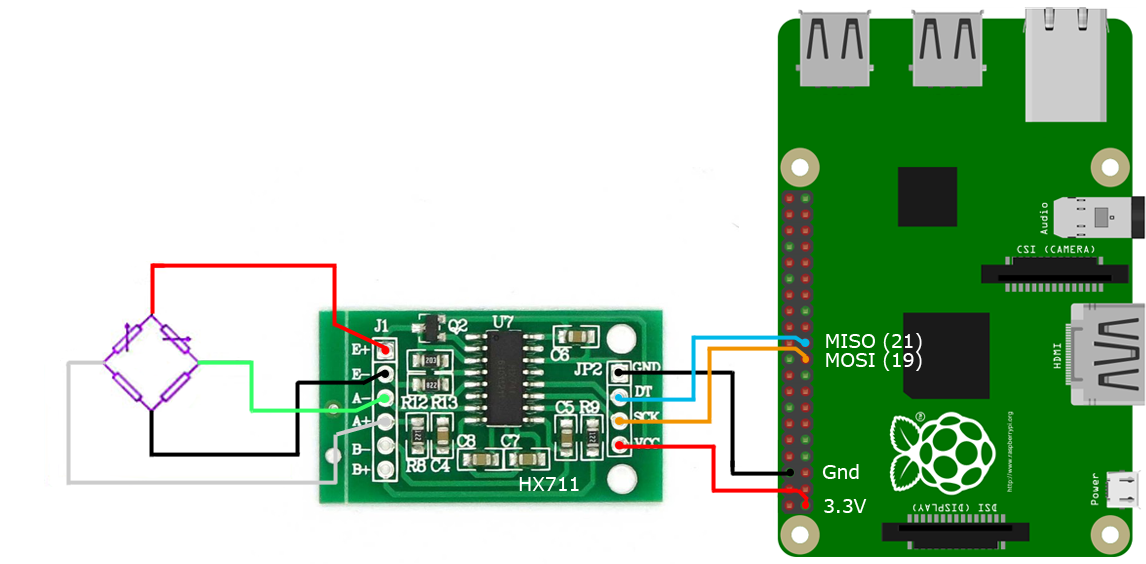
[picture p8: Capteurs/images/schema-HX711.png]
schema cablage HX711
 
Réaliser le câblage suivant le schéma ci-dessus 
# Installation
**Prérequis** : Cloner le dépôt
```
    pi@raspberry:~ $ git clone https://github.com/PhilippeSimier/Capteurs_I2C.git
    pi@raspberry:~ $ cd Capteurs_I2C/HX711
```
**Compilation & installation** : des programmes
```
    root@raspberry:~/home/pi/Capteurs_I2C/HX711 $ make all
    root@raspberry:~/home/pi/Capteurs_I2C/HX711 $ make install
    root@raspberry:~/home/pi/Capteurs_I2C/HX711 $ make clean
```
**Configuration et Etalonnage** de la balance

L'étalonnage  est  l'établissement de la relation entre une valeur connue et la valeur mesurée dans des conditions de mesure précises. En d'autres termes, l'étalonnage consiste à prendre un poids connu (p. ex. 1 kg) et d'établir la relation pour que la valeur affichée à l'écran corresponde à la valeur connue.

Ce que nous appelons « **poids** » est la force gravitationnelle de la terre exercée sur la force gravitationnelle de l'objet pesé. Plus un objet est éloigné du centre de la terre, plus le poids mesuré est faible. Par conséquent, un objet situé au niveau de la mer est légèrement plus lourd qu'à 1 000 mètres d'altitude – même si sa **masse**, elle, reste identique. 
Deuxièmement, l'accélération centrifuge provoquée par la rotation terrestre compense de manière subtile la force de la gravité. Cette accélération est à son maximum au niveau de l'équateur et diminue à mesure que l'on se rapproche des pôles. Donc, plus un objet s'éloigne de l'équateur, plus il devient lourd.
Le programme **etalonnage** permet de déterminer les paramètres de cette relation et de les enregistrer dans le fichier **configuration.ini**. 
```
root@raspberry:~/home/pi/Capteurs_I2C/HX711 $ ./etalonnage
Quelle est l'unité de mesure ? (g kg lb)
g
Quelle est la précision d'affichage : 1 ou 2 chiffres après la virgule
1
Donnez le gain souhaité : 128 ou 64 ?
128
```
**Tarage** de la balance

Le terme « **tare** » provient d'un ancien mot arabe signifiant « **déduction ou rejet** » et désigne le contenant renfermant l'article dont vous voulez connaître le poids. le programme **tarage** permet de réinitialiser l'affichage lorsque le contenant vide est posé sur le plateau de pesée.
```
root@raspberry:~/home/pi/Capteurs_I2C/HX711 $ ./tarage
root@raspberry:~/home/pi/Capteurs_I2C/HX711 $ ./main
```
Le programme **main** permet d'effectuer la pesé  en continu.

# Changelog

 **14/04/2018 :** Ajout du README . 
 **10/06/2018 :** Ajout programme d'étalonnage
> **Notes :**

> - Licence : **licence publique générale** 
> - Auteur **Philippe SIMIER Lycée Touchard Le Mans**
>  
<!-- TOOLBOX 

Génération des badges : https://shields.io/
Génération de ce fichier : https://stackedit.io/editor#

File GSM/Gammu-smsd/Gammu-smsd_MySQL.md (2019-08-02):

# Gammu-smsd  avec MySQL

## Installation de la base smsd

Avec phpmyadmin créer une base de données  **smsd**.
Créer les tables en important le fichier mysql.sql enregistré dans le répertoire  /usr/share/doc/gammu-smsd/examples/
```bash
root@raspberrypi3:~# cd /usr/share/doc/gammu-smsd/examples/
root@raspberrypi3:/usr/share/doc/gammu-smsd/examples# gunzip mysql.sql.gz
root@raspberrypi3:/usr/share/doc/gammu-smsd/examples# ls -l
total 16
-rw-r--r-- 1 root root 8174 mai   29  2013 mysql.sql
-rw-r--r-- 1 root root 1546 mai   29  2013 pgsql.sql.gz
-rw-r--r-- 1 root root  993 mai   29  2013 sqlite.sql.gz
```

## Configuration de Gammu-smsd

gammu-smsd lit la configuration à partir d'un fichier de configuration. Son emplacement peut être spécifié sur la ligne de commande (option -c), sinon le fichier par défaut **/etc/gammu-smsdrc** est utilisé.

La section **[gammu]** est la configuration d'une connexion au modem GSM
la section **[smsd]** configure le démon SMS lui-même.
Le paramètre **pin**  est facultatif, mais vous devez le définir si votre carte SIM après la mise sous tension nécessite un code PIN.

Exemple de fichier de configuration :
```
# Configuration file for Gammu SMS Daemon

[gammu]

port = /dev/ttyUSB0
connection = at
GammuLoc = fr_FR.UTF8
gammucoding = utf8

[smsd]
service = sql
driver = native_mysql
host = localhost
user = ruche
password = touchard72
database = smsd

logfile = syslog
# Increase for debugging information
debuglevel = 0
RunOnReceive = /home/pi/Ruche/SMSDreceive.sh
pin = 0000

```

## Démarrer le démon smsd

```bash
pi@raspberrypi3:/etc $ sudo service gammu-smsd start

```

## Vérifier l'état du démon gammu_smsd
```bash
root@raspberrypi3:~# sudo service gammu-smsd status
● gammu-smsd.service - LSB: Gammu SMS daemon
   Loaded: loaded (/etc/init.d/gammu-smsd)
   Active: active (running) since ven. 2019-08-02 11:05:06 CEST; 4s ago
  Process: 14701 ExecStop=/etc/init.d/gammu-smsd stop (code=exited, status=0/SUCCESS)
  Process: 14845 ExecStart=/etc/init.d/gammu-smsd start (code=exited, status=0/SUCCESS)
   CGroup: /system.slice/gammu-smsd.service
           └─14850 /usr/bin/gammu-smsd --daemon --user gammu --pid /var/run/gammu-smsd.pid

août 02 11:05:06 raspberrypi3 gammu-smsd[14850]: Connected to Database: smsd on localhost
août 02 11:05:06 raspberrypi3 gammu-smsd[14850]: Execute SQL: SELECT  `ID` FROM outbox LIMIT 1
août 02 11:05:06 raspberrypi3 gammu-smsd[14850]: Execute SQL: SELECT  `ID` FROM outbox_multipart LIMIT 1
août 02 11:05:06 raspberrypi3 gammu-smsd[14850]: Execute SQL: SELECT  `ID` FROM sentitems LIMIT 1
août 02 11:05:06 raspberrypi3 gammu-smsd[14850]: Execute SQL: SELECT  `ID` FROM inbox LIMIT 1
août 02 11:05:06 raspberrypi3 gammu-smsd[14850]: Execute SQL: SELECT `Version` FROM gammu
août 02 11:05:06 raspberrypi3 gammu-smsd[14850]: Database structures version: 13, SMSD current version: 13
août 02 11:05:06 raspberrypi3 gammu-smsd[14850]: Connected to Database native_mysql: smsd on localhost
août 02 11:05:06 raspberrypi3 gammu-smsd[14850]: Created POSIX RW shared memory at 0x76f2c000
août 02 11:05:06 raspberrypi3 gammu-smsd[14850]: Starting phone communication...
```
Le démon fonctionne correctement si la ligne Starting phone communication est affichée. Dans le cas contraire il y a peut être un problème de version !

## Envoyer un SMS 

**gammu-smsd-inject** est un programme qui **met en file d'attente le message** , qui sera ensuite envoyé par le démon à l'aide du modem GSM connecté.

Injecter un **message texte** jusqu'à 160 caractères standard:
```bash
root@raspberrypi3:/usr/share/doc/gammu-smsd/examples# gammu-smsd-inject TEXT 0689744235 -text "Nous sommes le `date`"
gammu-smsd-inject[14265]: Connected to Database: smsd on localhost
gammu-smsd-inject[14265]: Connected to Database native_mysql: smsd on localhost
gammu-smsd-inject[14265]: Written message with ID 1
Written message with ID 1

```

## Changelog

 **02/08/2019 :** Ajout gammu-smsd avec mysql  

> **Notes :**

> - Licence : **licence publique générale** 
> - Auteur **Philippe SIMIER Lycée Touchard Le Mans**
>  
<!-- TOOLBOX 

Génération des badges : https://shields.io/
Génération de ce fichier : https://stackedit.io/editor#

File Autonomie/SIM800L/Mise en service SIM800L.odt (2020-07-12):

Aide mise en œuvre SIM800L

## Mise en service

Insérer la carte SIM dans son emplacement, attention au sens, le biseau reste à l’extérieur.

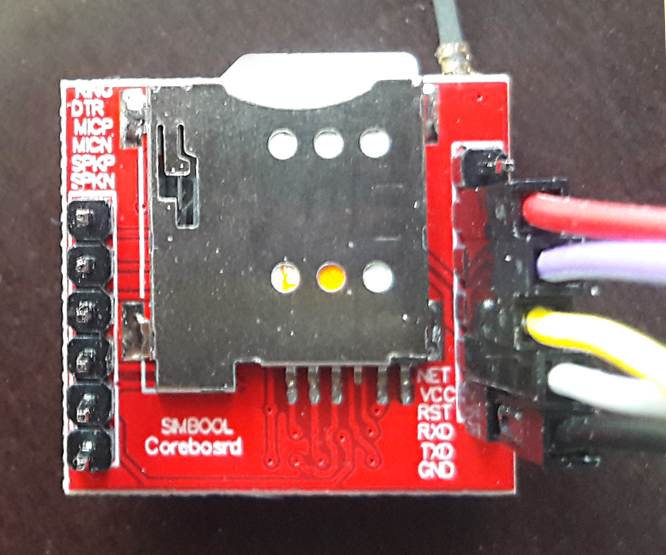
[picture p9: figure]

Connecter l’antenne fournie.

La broche NET correspond à l’antenne tir-bouchon que nous n’utiliserons pas.

Brancher l’alimentation et la liaison série sur le connecteur J13 de la carte snir hat.

Souder un condensateur 4700 µF placé entre Vin et GND .

Puis mettre sous tension la raspberry.

## Interprétation du voyant rouge sur la carte

Lors de la mise sous tension la LED rouge du modem clignote toute les 1 seconde, puis lorsque le réseau GSM est détecté clignote brièvement une fois toutes les 4 secondes.

Si la LED rouge clignote 9 8 ou 7 fois de façon continue avec une pause, alors vous avez un problème d’alimentation ou de connexion au réseau. Le courant est insuffisant. Sachez que Le modem SIM800L absorbe des pointes de courant pouvant aller jusqu’à 2A. Remarque pour ma part j’ai été obligé de supprimer la diode 1N4004 et d’alimenter directement en 5V le modem.

## tests avec les commande AT

Pour tester le modem nous utiliserons minicom.

Avant d’exécuter minicom nous devons stopper le démon gammu_smsd

root@pi3PSR:/home/pi# service gammu-smsd stop

Puis lancer minicom

root@pi3PSR:/home/pi# minicom -s

Régler le port série sur ttyS0

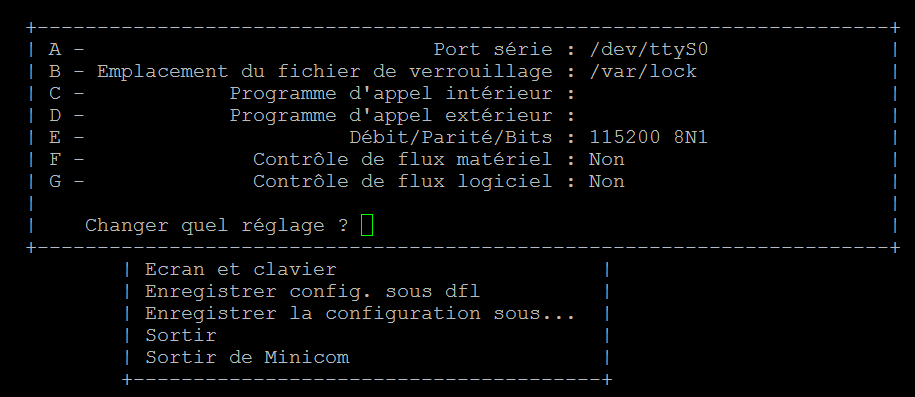
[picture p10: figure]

Vérifier la liaison série tapez la commande at en lettres majuscules ou minuscules

at

OK

Vérifier le code SIM

at+cpin?

+CPIN: READY

OK

Tester la présence du réseau GSM

at+creg?

+CREG: 2,1,"4400","21C1"

OK

La valeur 2 indique que le modem est enregistré sur le réseau. Les éléments d'information d'emplacement <lac> "4400" et <ci> "21C1" sont retournés uniquement lorsque <n> = 2

## Mesurer la qualité du signal

La commande at+csq permet de connaître le niveau reçu du signal du signal émis par la station de relais GSM la plus proche (avec le taux d’erreur). 99 correspond à un niveau inconnu ou non détectable.

at+csq

+CSQ: 29,0

OK

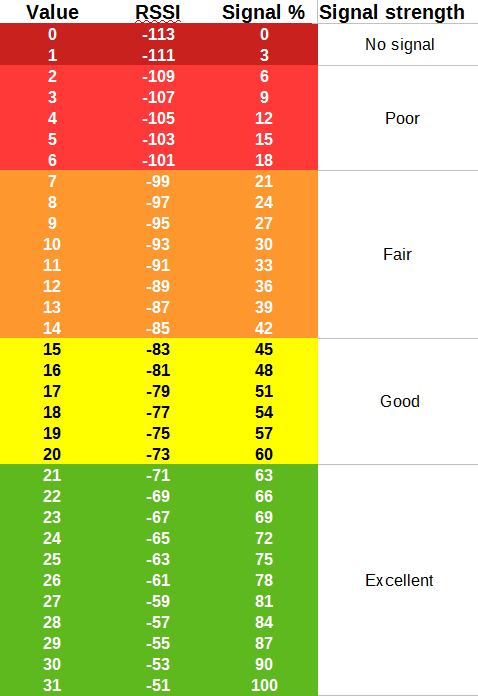
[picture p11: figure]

la valeur renvoyée peut être convertie en RSSI.

En 3G le RSSI varie usuellement de −113 dBm à −51 dBm selon la distance avec l'antenne émettrice.

Le décibel par rapport au milliwatt est noté dBm.

Il exprime une puissance par rapport à une référence. Cette référence est 1 milliwatt sur une impédance bien précise.

En radio 1 mW correspond à 0 dBm sur 50 Ohms, soit 223,6 mV.

dBm = 10 x Log P (avec P en milliwatt)

0 correspond à un rssi de -113

1 correspond à un rssi de -111

Chaque division correspond à un pas de 2dBm.

## Envoyer un SMS

at+cmgf=1

OK

at+cmgs="0689744235"

> test avec minicom

+CMGS: 182

OK

at+cmgf=1 Passage en mode texte

Envoyer un message SMS saisir la commande AT+CMGS="XXXXXXXXX" puis enter le modem répond en affichant le prompt > saisir le message enter pour passer à la ligne, puis ctrl Z pour envoyer.

## La jungle des commandes AT

En voici une sélection parfaitement arbitraire :

ati

SIM800 R14.18

OK

ati renvoie la réference du module

at+gsn

863576049060267

OK

at+gsn donne le numéro IMEI

at+cnum

+CNUM: "4D657373616765726965","+33768869503",145,0,4

OK

at+cnum donne le numéro de téléphone associé à la carte SIM

at+cbc

+CBC: 0,100,5168

OK

at+cbc donne l’état de la batterie 0 pas en charge, 100% chargée, Tension actuelle 5,168 V

## Utiliser le réseau GPRS

Il est possible de consulter une page web et récupérer son contenu pour pouvoir l’afficher dans le terminal. Pour cela, on utilise le réseau GPRS .

Access Point Name ou APN, appelé aussi identifiant du point d'accès réseau, est un identifiant qui permet à un utilisateur de téléphonie mobile d'un réseau 2G, 3G ou 4G de se connecter à Internet en identifiant la Gateway GPRS Support Node (GGSN pour la 2G et la 3G)

Pour une carte SIM Free, l’APN a renseigné est tout simplement "free". Pour d’autres opérateurs, il se peut qu’il y ai un identifiant et un mot de passe à renseigner.

AT+CGATT ? +CGATT : 1 Cherche le nombre de réseau disponible

AT+SAPBR=3,1,”CONTYPE”,”GPRS” OK Configure le profil 1, type de connexion internet : GPRS

AT+SAPBR=3,1,”APN”,”free” OK Configure le réseau APN

AT+SAPBR=1,1 OK Tentative de connexion GPRS

AT+HTTPINIT OK Initialisation

AT+HTTPPARA=”CID”,1 OK Configuration http

AT+HTTPPARA=”URL”,”” OK Configure l’adresse URL

AT+HTTPACTION=0 OK Lance la session

AT+HTTPREAD +HTTPREAD :<date_len>, Lis les données DATA du serveur http

AT+HTTPTERM OK Fin

AT+CIFSR Retourne l’adresse IP

http://tpil.projet.free.fr/2016/ArduinoGSM.html

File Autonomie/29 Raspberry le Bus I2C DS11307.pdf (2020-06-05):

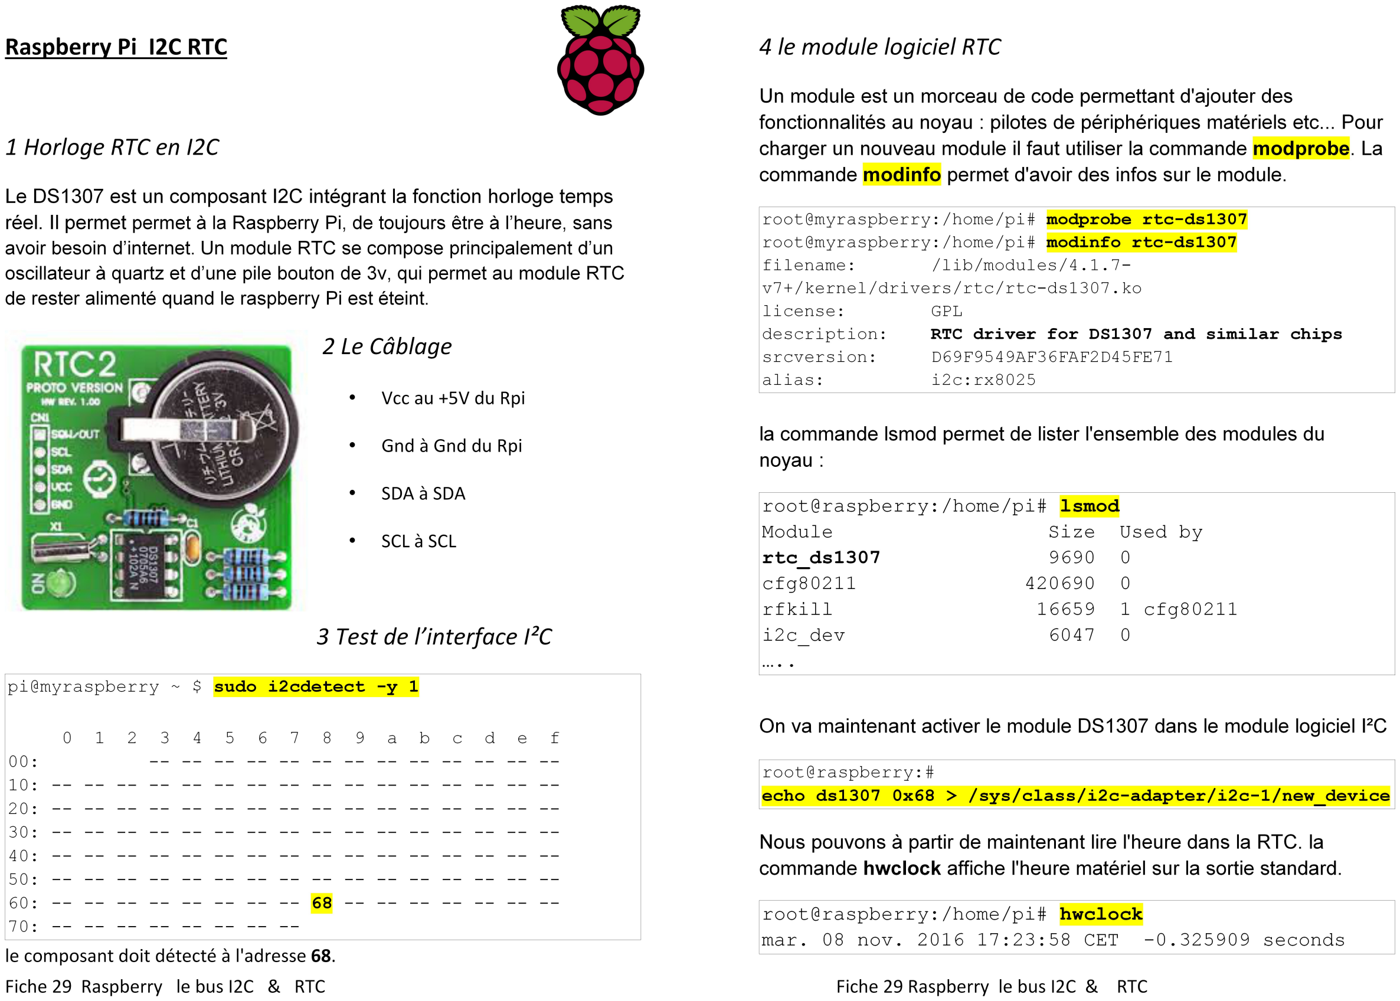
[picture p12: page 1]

hwclock -w Met l'horloge matérielle à l'heure système. Cette commande doit être éxécutée après le changement de la pile bouton 3V.
hwclock -s C'est la commande inverse de la précédente elle met l'heure système à l'heure de l'horloge matérielle. Cette commande doit être exécutée au démarrage lorsque le réseau n'est pas présent.

## 5 chargement automatique du module

Il est possible de spécifier des modules à charger au démarrage, même si le périphérique à piloter par un module n'a pas été trouvé. La liste des modules à charger explicitement au démarrage est dressée dans le fichier /etc/modules. Chaque ligne de ce fichier représente un module à charger, sauf les lignes vides ou commençant par un #.

# /etc/modules: kernel modules to load at boot time.

# This file contains the names of kernel modules that should be loaded

# at boot time, one per line. Lines beginning with "#" are ignored.

# Parameters can be specified after the module name.

snd-bcm2835
i2c-dev
#chargement du module horloge temps réel

rtc-ds1307

Il faut maintenant créer le périphérique DS1307 au démarrage en modifiant le fichier /etc/rc.local :

# By default this script does nothing.

# Print the IP address

_IP=$(hostname -I) || true
if [ "$_IP" ]; then
printf "My IP address is %s\n" "$_IP"
fi

echo ds1307 0x68 > /sys/class/i2c-adapter/i2c-1/new_device
sudo hwclock -s

exit 0

C’est terminé, désormais le Raspberry Pi sera constamment à l’heure, qu’il soit connecté à internet ou pas !

Fiche 29 Raspberry le bus I2C & RTC | Fiche 29 Raspberry le bus I2C & RTC

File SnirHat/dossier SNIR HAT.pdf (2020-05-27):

SNIR HAT

Le circuit imprimé SNIR HAT est une carte fille pour RPI 3 supportant les modules suivants

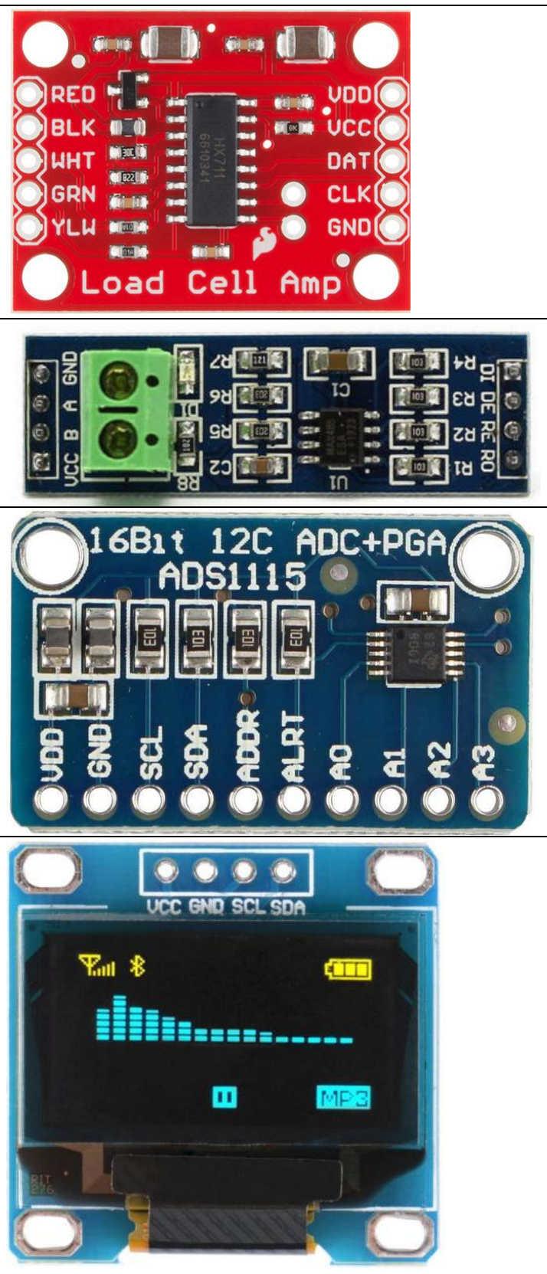
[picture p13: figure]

Conditionneur des capteurs de force HX711 BUS SPI Connecteur U1

Module RS485 (MAX485) UART ttyAMA0 Connecteur U2

Convertisseur analogique numérique 16 bits ADC 16 bits ADS1115 BUS I²C Connecteur J11

OLED display module 0.96″ inches Résolution 128X64 BUS I²C Connecteur J3

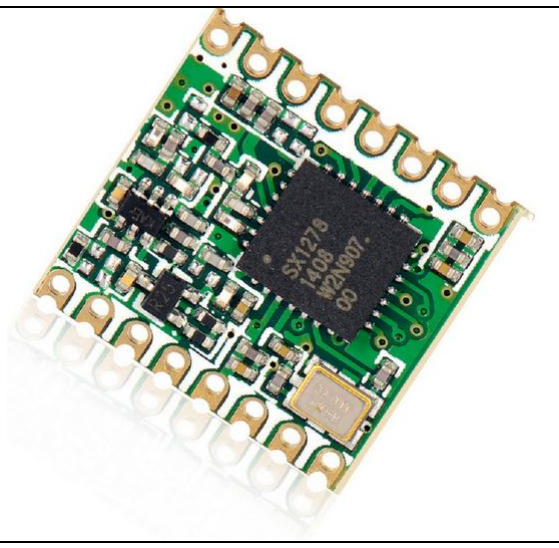
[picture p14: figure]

LoRa Wireless module SX1278 433MHZ Bus SPI + GPIO Module à souder, Emplacement U3

Sim800L Quad-band 850/900/1800/1900MHz Connect onto any global GSM network with any 2G SIM Make and receive voice calls using a headset or an external 8 speaker and electret microphone Send and receive SMS messages Send and receive GPRS data (TCP/IP, HTTP, etc.) Scan and receive FM radio broadcasts Lead out buzzer and vibrational motor control port AT command interface with "auto baud" detection UART ttyAMA0 Connecteur J13

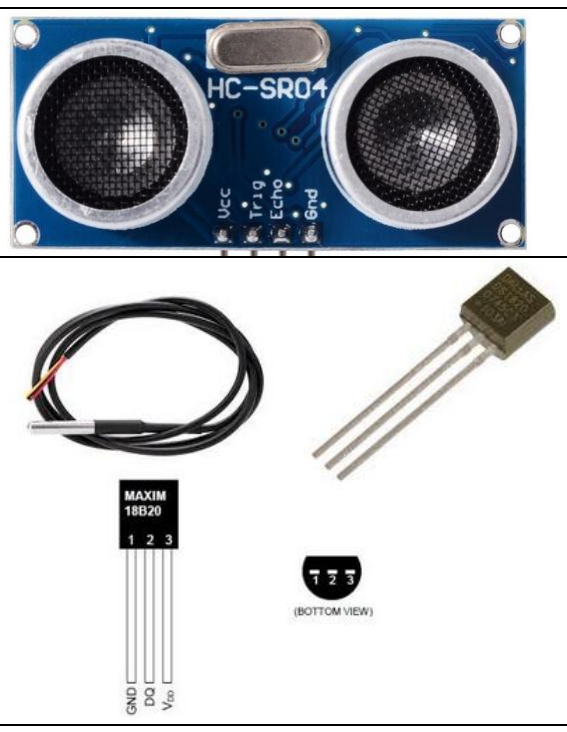
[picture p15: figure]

Capteur ultra-son HC-SR04 GPIO Connecteur J10

Capteur de température one Wire DS18S20 ou DS18B20 -55 °C à +125 °C TO-92 GPIO Emplacement U4

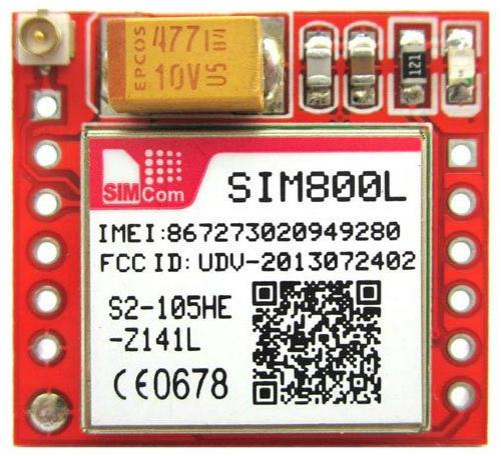
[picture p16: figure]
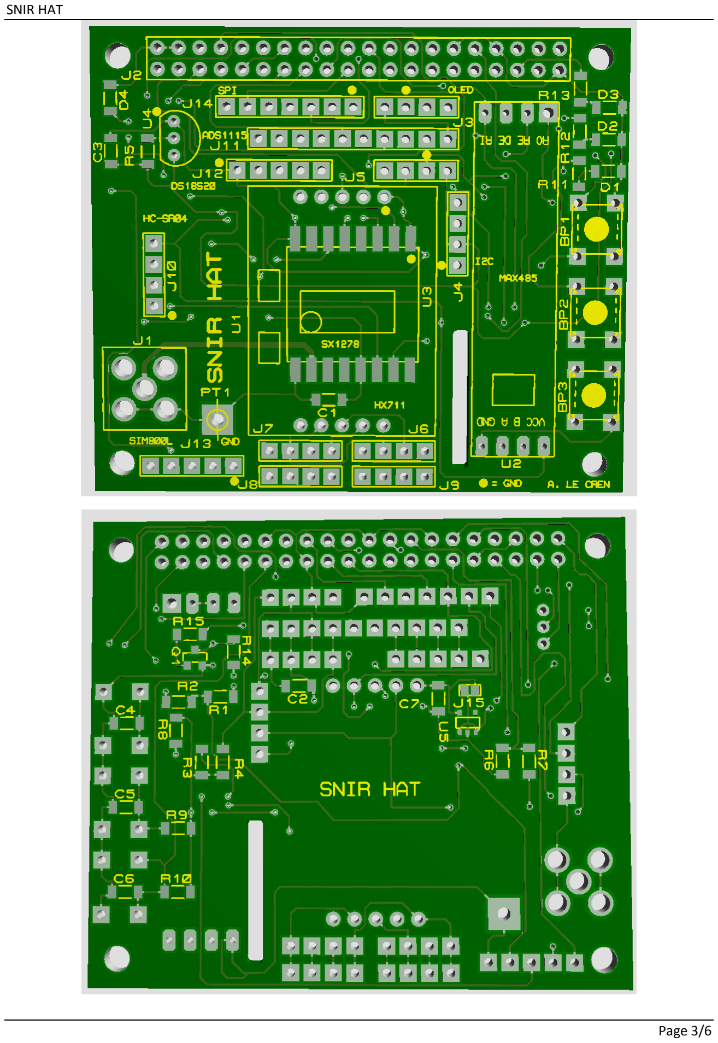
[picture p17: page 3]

# GPIO HEADER

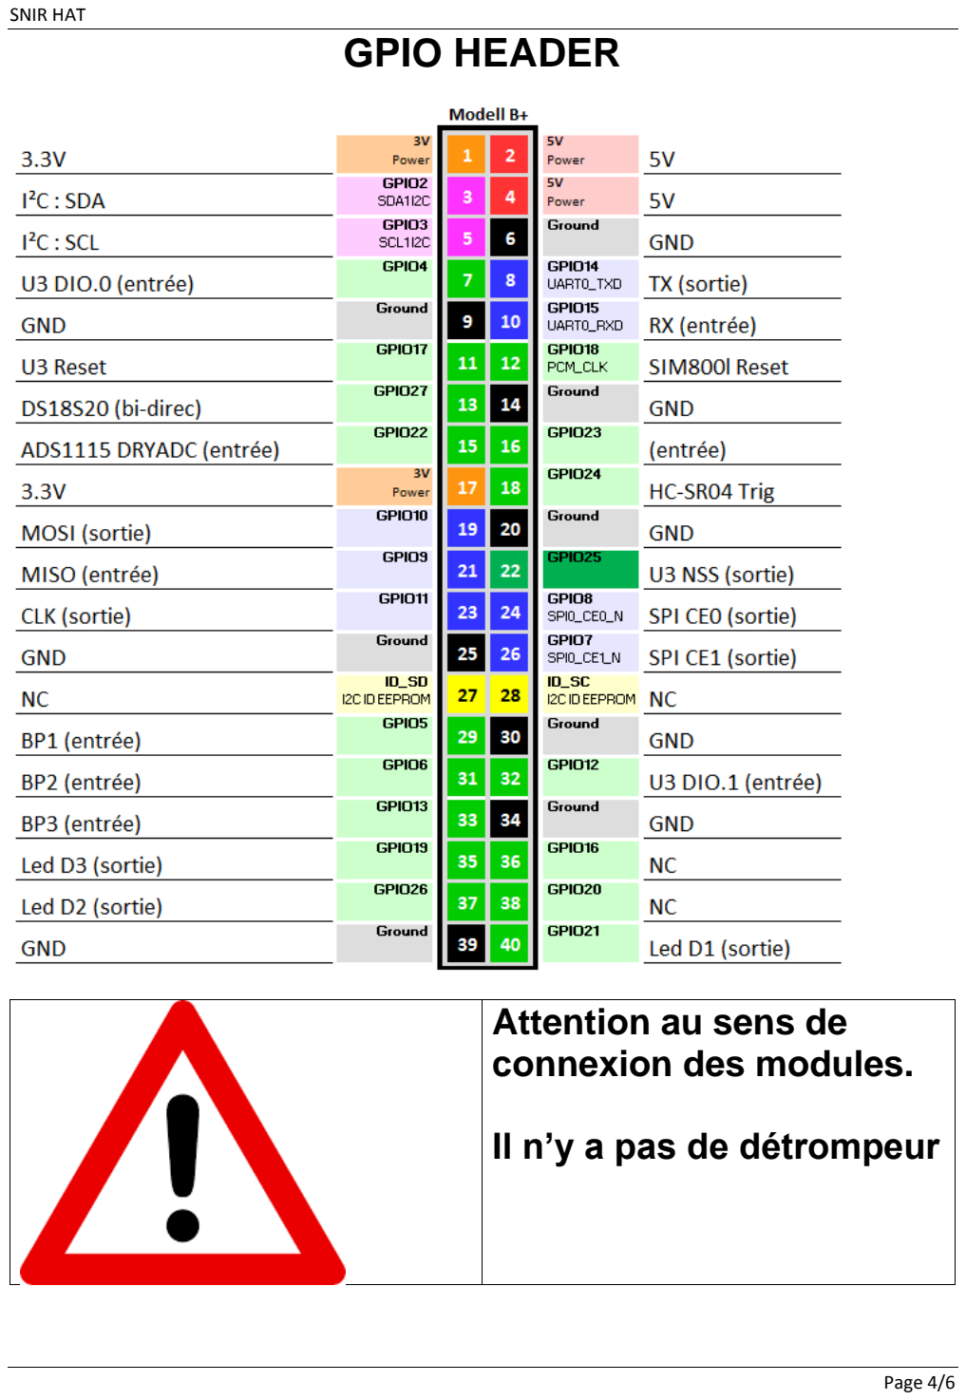
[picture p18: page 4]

# Attention au sens de

connexion des modules.

# Il n’y a pas de détrompeur

# Bill Of Materials

Category | Quantity | Reference | Value | CASE
Resistors | 2 | R1, R6 | 3.3K | SMD 1206
Resistors | 2 | R2, R7 | 1.8K | SMD 1206
Resistors | 7 | R3, R4, R8-R10, R14, R15 | 10k | SMD 1206
Resistors | 1 | R5 | 4.7K | SMD 1206
Resistors | 3 | R11-R13 | 1K | SMD 1206
Capacitors | 7 | C1-C7 | 100nF | SMD 1206
Integrated Circuits | 1 | U1 | HX711 | Module
Integrated Circuits | 1 | U2 | MAX485 | SOIC 8
Integrated Circuits | 1 | U3 | SX1278 | Module
Integrated Circuits | 1 | U4 | DS18S20 | TO-92
Integrated Circuits | 1 | U5 | LP5907-3.3 | SOT23-5
Transistors | 1 | Q1 | 2N7002 | SOT23
Diodes | 3 | D1-D3 | LED | SMD 1206
Diodes | 1 | D4 | 1N4007 | SMD 1206
Miscellaneous | 3 | BP1-BP3 | BP
Miscellaneous | 1 | J1 | SMA | FEM 90°
Miscellaneous | 1 | J2 | HE40 | FEM
Miscellaneous | 8 | J3-J10 | CONN-SIL4 | FEM
Miscellaneous | 1 | J11 | CONN-SIL10 | FEM
Miscellaneous | 2 | J12, J13 | CONN-SIL5 | FEM
Miscellaneous | 1 | J14 | CONN-SIL7 | FEM
Miscellaneous | 1 | J15 | PAD
Miscellaneous | 1 | PT1 | GND | TEST POINT

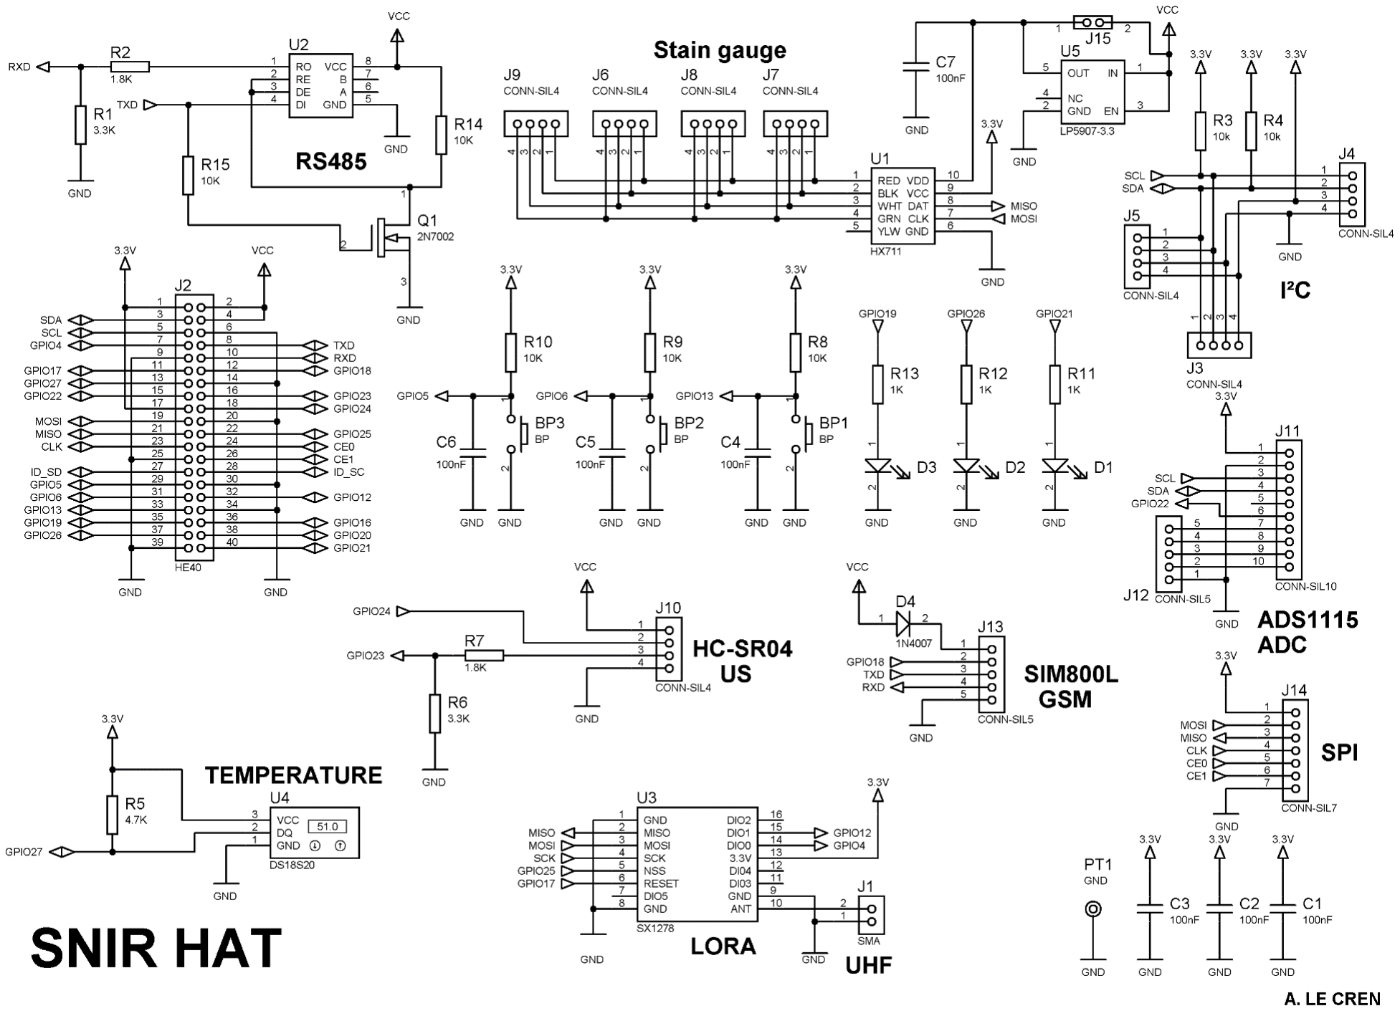
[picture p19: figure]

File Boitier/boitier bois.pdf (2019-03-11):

# Boîtier pour ruche connectée

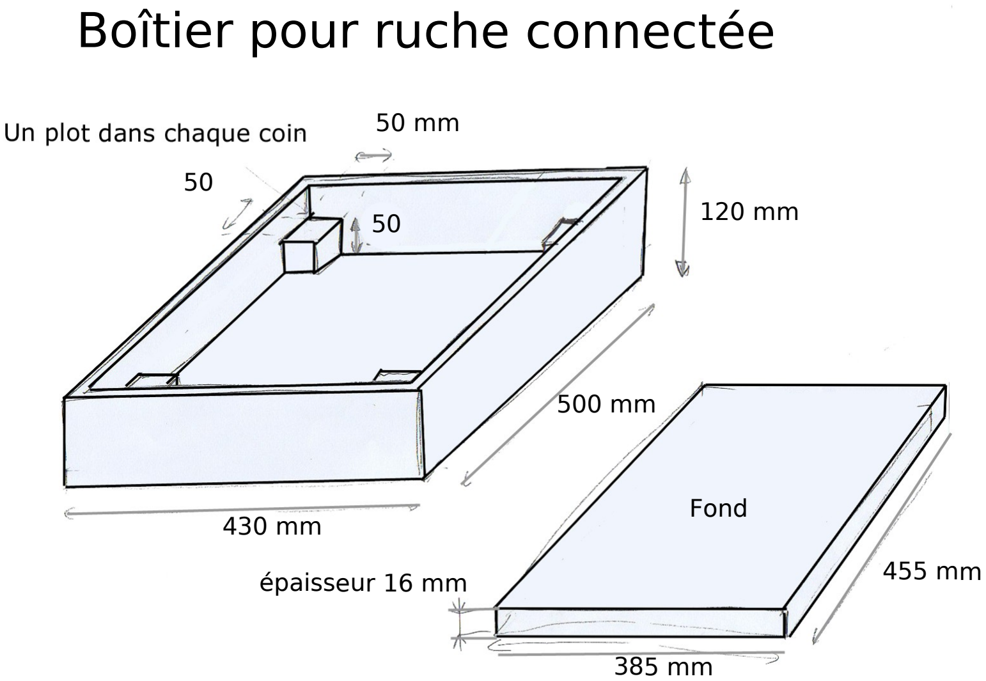
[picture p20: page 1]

épaisseur 16 mm

385 mm

50

50

Fond

455 mm

430 mm

500 mm

120 mm

50 mm

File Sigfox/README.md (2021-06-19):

# Sigfox

## La carte SNOC BRKWS01

Le breakout **BRKWS01** est une carte  SigFox , basée sur le module Wisol SFM10R1. Cette carte permet  d'utiliser le réseau LPWan SigFox   pour la transmission de données. Le réseau SigFox permet d'envoyer des messages de **12 octets** à raison de 140 messages par jour.

## Activer le module sur le site SigFox

Afin de permettre l’accès au réseau SigFox, il est nécessaire créer un compte utilisateur. 
Le compte utilisateur permet d'activer des modules. l'identifiant ID et le code PAC  de la carte SNOC sont nécessaires pour créer une nouvelle activation. Cette activation autorise le module à émettre et recevoir des données sur le réseau SigFox . La carte BRKWS01 est vendu avec un an d’abonnement découverte inclus.
Quand votre inscription est terminée. Il reste à la valider en suivant le lien que vous avez reçu dans un mail à l’adresse que vous avez fournie. Cliquez sur le lien dans le message pour terminer votre inscription.  Vous devrez alors définir un mot de passe.

[lien vers la page d'activation d'un module](https://buy.sigfox.com/activate)

## Envoi de données via SigFox

Le module est contrôle avec des commandes  AT envoyées sur des broches TX / RX. La communication série: se fait à **9600** bauds, avec **8 bits par caractères**, 1 bit de stop, **sans parité** écho local.

Les commandes AT se font en **majuscules**

Test de Communication:	

    AT
    OK

Récupérer le Module ID:	

    AT$I=10

Récupérer le code PAC:	

    AT$I=11

Envoyer un message :	(Valeur Hexadécimal) donc un nombre de caractères paire

    AT$SF=001122AABBEEFF
    OK

Envoyer un message SIGFOX avec trame de reception:	(Valeur Hexadécimal)

Envoyer 01 .. 06, en attendant une liaison descendante

    AT$SF=010203040506,1                   
    ERR_SFX_ERR_SEND_FRAME_WAIT_TIMEOUT      
     
Réponse obtenue lorsque aucune liaison descendante n'est reçue

Même chose obtenue quand une liaison descendante est reçue avec les 8 octets.

    AT$SF=010203040506,1                  
    OK 
    RX=00 00 0A E1 00 00 FF 8F

## Lire les messages reçus sur l'agrégateur Sigfox

Les messages émis par les devices sont stockés sur l'aggrégator SigFox. Il est possible de les consulter en se connectant sur le site Sigfox côté **backend**.

[Lien vers le backend SigFox](https://backend.sigfox.com/auth/login)

Cliquer sur l'onglet **DEVICE** un tableau des devices activés s'affiche. 
Cliquer sur le **Device ID**  puis sur **MESSAGES** pour afficher la liste des messages envoyés par le module sélectionné.
Chaque message est horodaté.

## Activation du callback

A réception du message, le serveur SigFox va transférer les données vers un serveur désigné par l’utilisateur. C’est ce qu’on appelle un “**callback**”.
Dans l’onglet “**DEVICE TYPE**” du site SigFox, cliquer sur le nom de la carte, pour faire apparaître dans la colonne de gauche un menu comportant l’option **CALLBACKS**.
Pour créer un nouveau callback cliquer sur le bouton new (en haut à droite)
Choisir l'option **Custom callback**

### Configuration d'un DATA UPLINK

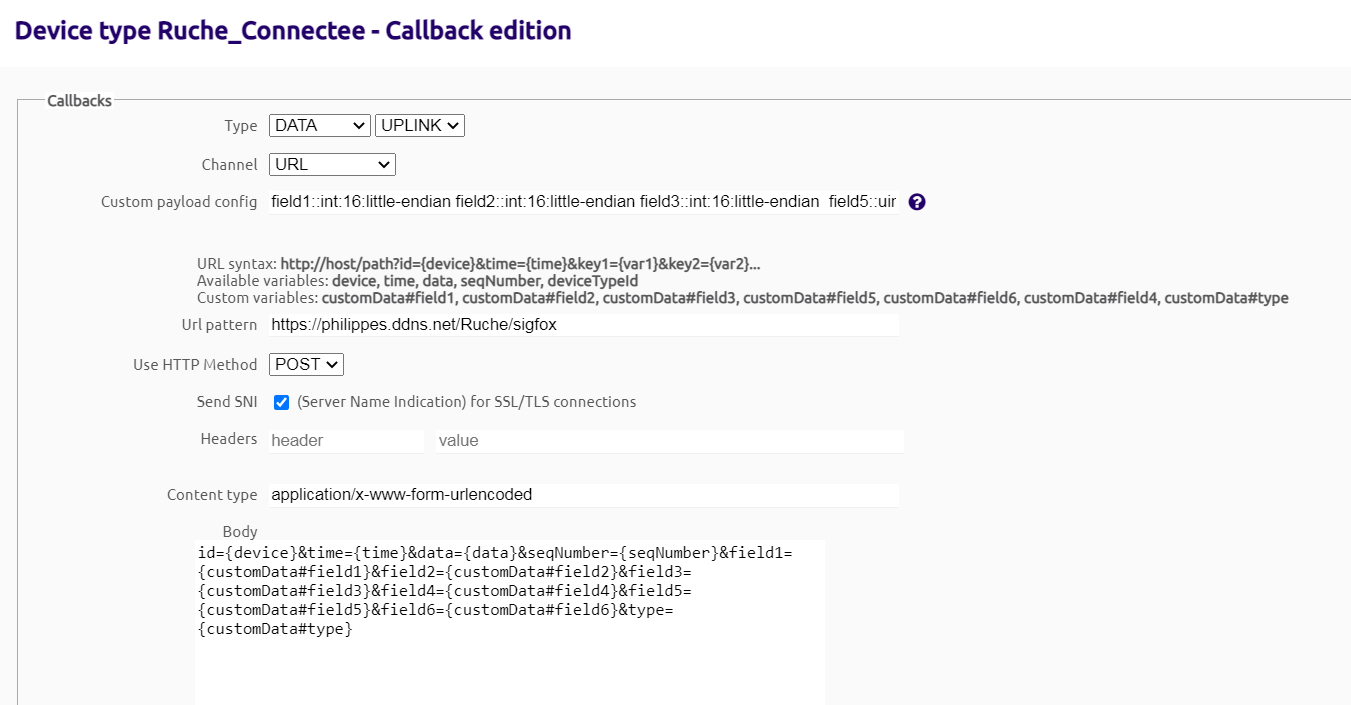
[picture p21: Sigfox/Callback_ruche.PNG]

**Custom payload config :**
Ce champ permet de décoder la trame reçue et de la transmettre au serveur Aggregator. 
```
field1::int:16:little-endian field2::int:16:little-endian field3::int:16:little-endian  field5::uint:16:little-endian field6::int:16:little-endian field4::uint:8 type::uint:8
```
Les données sont renvoyées au serveur Aggregator via  la méthode POST.
```
id={device}&time={time}&data={data}&seqNumber={seqNumber}&field1={customData#field1}&field2={customData#field2}&field3={customData#field3}&field4={customData#field4}&field5={customData#field5}&field6={customData#field6}&type={customData#type}

```

### Configuration d'un service data_advanced

Le service data advanced permet de d'envoyer des informations sur la qualité de la transmission (lqi) et sur la localisation. Ces informations sont codées au format JSON.
 
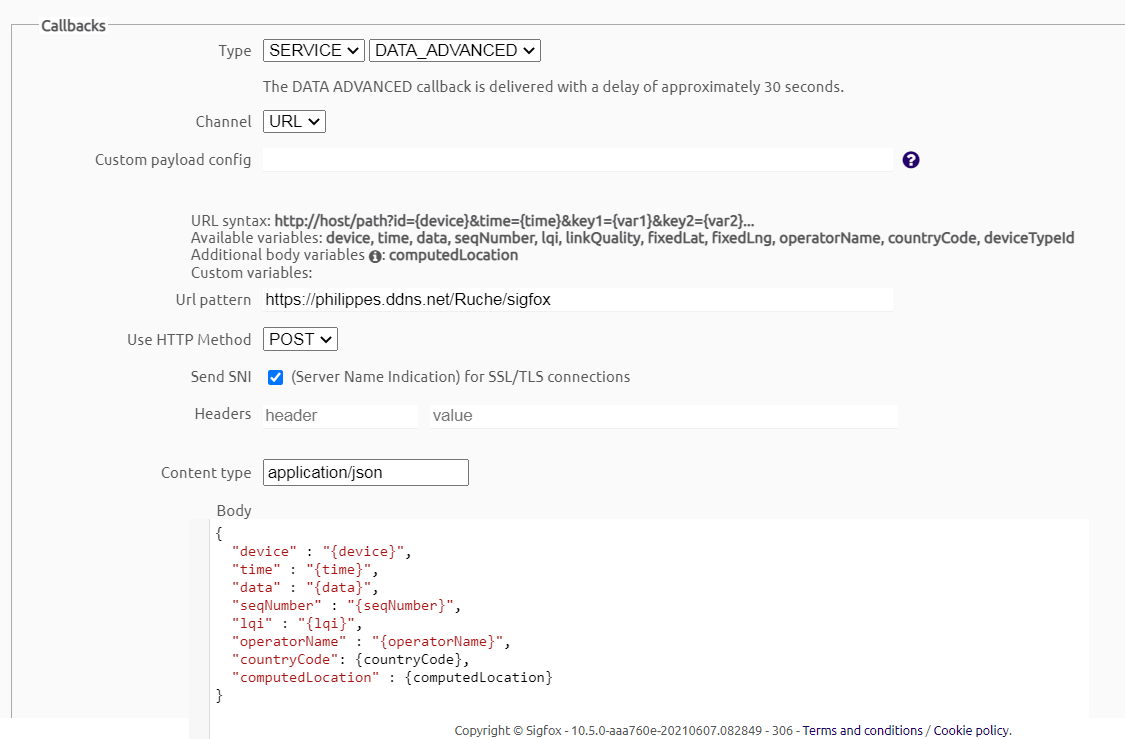
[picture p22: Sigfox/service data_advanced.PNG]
Data UpLink


```
{
  "device" : "{device}",
  "time" : "{time}",
  "data" : "{data}",
  "seqNumber" : "{seqNumber}",
  "lqi" : "{lqi}",
  "operatorName" : "{operatorName}",
  "countryCode": {countryCode},
  "computedLocation" : {computedLocation} 
}
```
### Configuration du service status

Un message de service est envoyé une fois par jour par le modem **sigfox**. Ce message contient la température et la tension d'alimentation. 
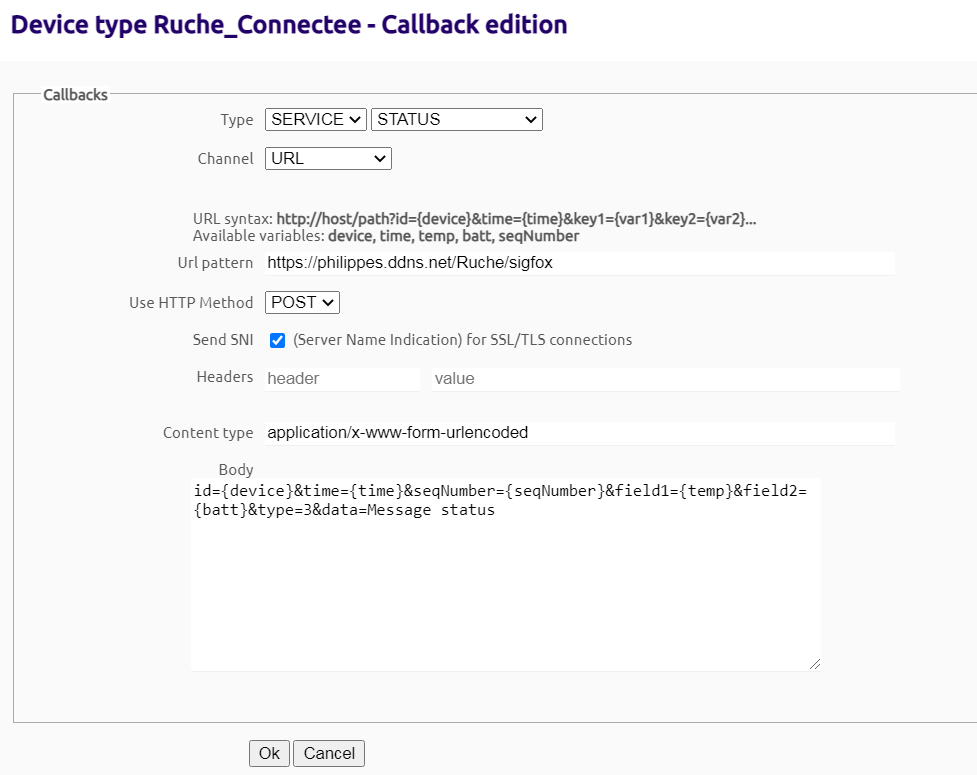
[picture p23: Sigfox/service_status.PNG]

```
id={device}&time={time}&seqNumber={seqNumber}&field1={temp}&field2={batt}&type=3&data=Message status
```

## Diagramme de classe Sigfox

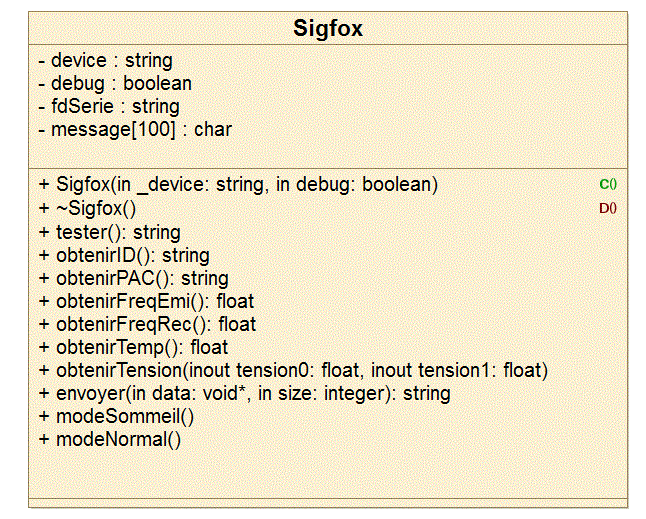
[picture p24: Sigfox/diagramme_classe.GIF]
Diagramme de classe


### Les méthodes publiques
 - **Sigfox** Le constructeur de l'objet avec en  paramètres  le nom du port série utilisé, **debug** un booléen pour activer le mode débogage.
 - Le constructeur ouvre le port série et fixe le débit de communication à 9600 bauds.
 - **~Sigfox**  le destructeur ferme le port série utilisé. 
 - **tester** Envoie une commande AT sur la liaison série et lit les données entrantes, le module renvoie OK si le transmetteur répond.
 - **obtenirID** Permet d'obtenir l'ID du transmetteur  connecté.
 - **obtenirPAC** Permet d'obtenir le code PAC du transmetteur connecté.
 - **obtenirTemp** Permet d'obtenir la température interne du transmetteur connecté.
 - **envoyer** Envoie un message codé en hexa sur le réseau Sigfox. Un message Sigfox est composé au maximum de 12 octets. Cette méthode attend la fin de l'émission. Elle renvoie  un string OK. Le fait de recevoir la réponse OK ne confirme pas la réception du message par une ou plusieurs stations de base sigfox. 

[le code exemple](https://github.com/PhilippeSimier/Ruche/blob/master/Sigfox/main.cpp)

## Emission des données 

Deux programmes permettent d'envoyer les données vers l'aggrégator 

 - **mesuresSigfox.cpp** pour le suivi des grandeurs relatives à la ruche
 - **batterySigfox.cpp** pour le suivi de la batterie.
 ### Configuration du crontab 
 Le crontab est configuré pour envoyer toute les demi-heures.
 ```
 */30 * * * * /opt/Ruche/bin/mesuresSigfox >/dev/null 2>&1
15,45 * * * * /opt/Ruche/bin/batterySigfox >/dev/null 2>&1
 ```

# Changelog

**09/08/2020 : ** Ajout du README . 

> **Notes :**

> - Licence : **licence publique générale** 
> - Auteur **Philippe SIMIER** Lycée Touchard Le Mans
>  
<!-- TOOLBOX 

Génération des badges : https://shields.io/
Génération de ce fichier : https://stackedit.io/editor#
example : https://github.com/adrien3d/IO_WSSFM10-Arduino

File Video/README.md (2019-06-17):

# Webcam

Une caméra est installée pour surveiller le flux entrant et sortant des abeilles. L'idée est simple. Nous allons capturer des images toutes les **3 secondes** et les partager via une interface Web ce qui nous permettra de voir à distance  virevolter les abeilles. La méthode consiste à capturer des images à intervalles régulier avec la commande **raspistill**, puis à les diffuser grâce au serveur web Apache.

### 1 Configuration d'une partition mémoire en RAM 

Étant donné que toute carte SD a des ressources limitées pour les cycles d'écriture, nous allons  créer une « partition » directement dans la RAM qui est spécialement conçue pour encaisser de nombreux cycles d’écritures. Nous utiliserons ce lecteur ram en tant que lecteur de stockage temporaire pour enregistrer les images. 

Commençons par créer un dossier pour cela:
```
root@raspPi3plus:/home/pi# mkdir /var/tmp/ram_drive
```
Il convient d’éditer le fichier /etc/fstab qui gère les points de montages du système. 
```
root@raspPi3plus:/home/pi# nano /etc/fstab
```
Ajouter la ligne suivante :
```
proc                  /proc       proc    defaults          0       0
PARTUUID=f0fb3126-01  /boot      vfat    defaults          0       2
PARTUUID=f0fb3126-02  /          ext4    defaults,noatime  0       1
tmpfs      /var/tmp/ram_drive tmpfs nodev,nosuid,size=10M 0 0
```
Maintenant montez le  système:
```
root@raspPi3plus:/home/pi# sudo mount -a
```
Vérifiez le montage:
```
root@raspPi3plus:/home/pi# df -h
Sys. de fichiers Taille Utilisé Dispo Uti% Monté sur
/dev/root           15G    9,7G  4,2G  70% /
devtmpfs           434M       0  434M   0% /dev
tmpfs              438M       0  438M   0% /dev/shm
tmpfs              438M     39M  400M   9% /run
tmpfs              5,0M    4,0K  5,0M   1% /run/lock
tmpfs              438M       0  438M   0% /sys/fs/cgroup
/dev/mmcblk0p1      43M     23M   21M  52% /boot
tmpfs               88M       0   88M   0% /run/user/1000
tmpfs               10M    724K  9,3M   8% /var/tmp/ram_drive

```
### 2 Script bash pour capturer des images

Nous allons créer un script qui sera lancé par le démon cron toutes les minutes. 
la période d'une minute ne suffit pas, nous avons besoin d'actualiser l'image toutes les 3 secondes. La solution est d'exécutée raspistill 20 fois dans le processus (60/20 = 3 secondes).
les images capturées sont  recopiées dans le répertoire vidéo sur le site WEB de la DMZ avec la commande **scp** (Secure copy). La commande scp permet de transférer des fichiers entre deux ordinateurs en utilisant le protocole de communication SSH. 
Pour ne pas demandé le mot de passe le serveur WEB  DMZ doit connaître la clé publique de la raspberry pi. Cette clé doit  être présente dans le fichier ~/.ssh/authorized_keys. 

```bash
#!/bin/bash

OUTPUT=/var/tmp/ram_drive/cam.jpg
OPTIONS='-t 1000 -w 1296 -h 972 -q 10 --exif none'

for i in $(seq 1 20)
do
  raspistill -a 4 -a "%d %B %Y %X" -ae 32,0xFF,0x000080 $OPTIONS -o $OUTPUT
  scp $OUTPUT root@172.18.58.9:/var/www/Ruche/video
  if [ $i != "20" ]
    then
      sleep 1
  fi
done

``` 

### Page Web

Créons une page Web qui actualisera l’image toutes les 3 secondes.
```
 <body>
	<?php require_once 'menu.php'; ?>
	<div class="container" style="padding-top: 65px;">
		<div class="row">
			<div class="col-md-12 col-sm-12 col-xs-12">
				<div >
			        <img src="" class="popin d-block mx-auto img-fluid"  id="photo" alt="Beehive on air" />
					
			    </div>  
				
			</div>
		</div>
		<?php require_once 'piedDePage.php'; ?>
	</div>

</body>
```
Le script qui réactualise l'image à l'écran.

```javascript
<script type="text/javascript">
"use strict";
function affiche(){
            var img = document.getElementById("photo");
            img.src = 'http://touchardinforeseau.servehttp.com/Ruche/video/cam.jpg?'+new Date().getMilliseconds();
		    console.log("rafraichissement : " + img.src);	
		}
		
 $(document).ready(function(){
				
   	affiche();
	setInterval(affiche, 3002);       // appel de la fonction affiche toutes les 3 secondes et 2 milliemes
});
</script>
```

### Changelog

 **07/06/2019 :** Ajout du README . 

> **Notes :**

> - Licence : **licence publique générale** 
> - Auteur **Philippe SIMIER Lycée Touchard Le Mans**
>  
<!-- TOOLBOX 

Génération des badges : https://shields.io/
Génération de ce fichier : https://stackedit.io/editor#
https://docplayer.fr/15188945-Le-traitement-d-images-avec-opencv.html

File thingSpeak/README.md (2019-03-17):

# API ThingSpeak

## Lecture des datas enregistrées dans un channel
Les noms des champs  associés à un channel peuvent être obtenues en interrogeant l'api  thingspeak avec la requête suivante.   Pour obtenir uniquement les informations sur le channel et les noms des champs associés, fixer le paramètre **results** à 0 (nombre de datas renvoyées = 0).
 
```html
https://api.thingspeak.com/channels/539387/feed.json?results=0
```
La réponse obtenue est un objet au format JSON:
```javascript
{"channel":{
	"id":539387,
	"name":"Mesures",
	"description":"mesures intérieures ...",
	"latitude":"47.92647",
	"longitude":"0.159561",
	"field1":"Weight (g)",
	"field2":"Temperature (°C)",
	"field3":"Pressure (hPa)",
	"field4":"Humidity (%)",
	"field5":"Illuminance (Lux)",
	"field6":"dew point (°C)",
	"field7":"Corrected Weight",
	"created_at":"2018-07-14T15:28:23Z",
	"updated_at":"2018-10-29T10:59:43Z",
	"elevation":"60.2",
	"last_entry_id":9635
	},
"feeds":[]
}
```

## Changelog

 **04/08/2018 :** Ajout du README . 
 **10/09/2018 :** Ajout du  script shell RaspbianOSsetup.sh
 
> **Notes :**

> - Licence : **licence publique générale** 
> - Auteur **Philippe SIMIER Lycée Touchard Le Mans**
>  
<!-- TOOLBOX 

Génération des badges : https://shields.io/
Génération de ce fichier : https://stackedit.io/editor#

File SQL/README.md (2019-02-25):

Schéma de la base data
===================
Un utilisateur (table **users**) possède un ou plusieurs objets ( table **things**).
Chaque objet est associé à un ou plusieurs canaux (table **channels**).  Un canal peut être associé à plusieurs objets. 
Chacun des canaux est nourri avec des mesures (table **feeds**).

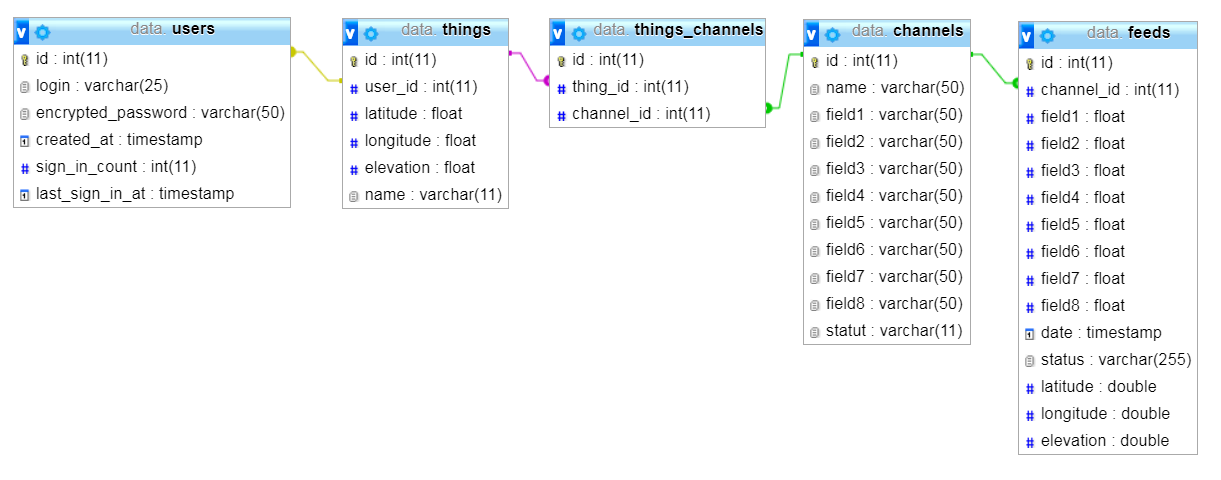
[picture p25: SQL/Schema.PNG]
schema base data


### Changelog

 **08/02/2019 :** Ajout du README . 

> **Notes :**

> - Licence : **licence publique générale** 
> - Auteur **Philippe SIMIER Lycée Touchard Le Mans**
>  
<!-- TOOLBOX 

Génération des badges : https://shields.io/
Génération de ce fichier : https://stackedit.io/editor#

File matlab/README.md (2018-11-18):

# Thing Speak - Matlab

## Présentation
ThingSpeak est à l’origine une **plate-forme IoT open source** dont l’objectif est de collecter, de stocker et de traiter des données générées par des objets connectés. En 2015, le projet a été repris par MathWorks. Depuis la plate forme a obtenue de nombreux services supplémentaires notamment une **intégration avec Matlab**. Elle permet aussi notamment de réagir lors de l’arrivée d’une donnée, ou encore de **programmer des actions automatiques**.

Les objets/capteurs communiquent leurs données à la plate-forme ThingSpeak au travers de requêtes HTTP. Un système de clés est présent pour assurer la sécurité des transmissions. Les données reçues sont  stockées dans une base de données relationnelle. L’insertion d’une donnée peut aussi être l’élément déclencheur d’une action comme par exemple l'exécution d’un script Matlab pour faire des opérations mathématiques ou envoyer une notification.

[Site web ThingSpeak](https://thingspeak.com)

## MATLAB Visualizations

Les tracés interactifs MATLAB® permettent de visualiser et d'explorer les données collectées dans un canal. Les diagrammes **nuage de points** permettent de mettre en évidence la corrélation entre les données. Les histogrammes permettent de représenter la **répartition** et la **dispersion** des données.

#### Exemple :
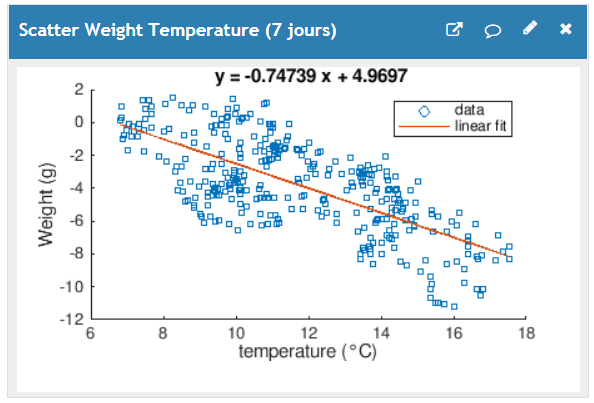
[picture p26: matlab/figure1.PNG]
dispersion température/poids


[Script Matlab Nuage de points Température/Poids](/matlab/dispersion_poids_temperature.m)

dispersion température/humidité

[Script Matlab Nuage de points Température/Humidité](/matlab/dispersion_temperature_humidity.m)

histogramme temps/poids

[Script Matlab Histogramme Température](/matlab/histogramme_temperature.m)

## Changelog

## Changelog

 **31/10/2018 :** Ajout du README . 

> **Notes :**

> - Licence : **licence publique générale** 
> - Auteur **Philippe SIMIER Lycée Touchard Le Mans**
>  
<!-- TOOLBOX 

Génération des badges : https://shields.io/
Génération de ce fichier : https://stackedit.io/editor#

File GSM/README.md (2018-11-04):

# Transmission de données via réseau GSM

## Présentation
La transmission de données via le **réseau GSM** convient particulièrement lorsque les mesures doivent être réalisées sur une ruche située dans un lieu isolé et éloigné. Un modem GSM  est alors raccordé au raspberry pi sur une prise USB. La transmission des données au modem se fait  via une liaison série. Le modem est piloté par un jeu de commandes standards Hayes appelé aussi commandes AT. Le modem GSM/GPRS intègre une carte SIM  avec un abonnement comprenant des appels limités à 2h mais permettant l'envoi de sms et de mms illimités. La plupart des opérateurs proposent des forfaits de ce genre pour 2€ par mois.

La norme GPRS spécifie le support de transmission de données en mode paquet sur GSM. Ce support permet de transmettre des messages courts appelés SMS à travers des canaux radio GPRS.

## Topologie
topologie transmission GSM

La passerelle est  composée d'une raspberry pi et d'un modem GSM. Elle joue le rôle d'intermédiaire en se plaçant entre une ruche connectée et la platforme IOT thingSpeak  pour permettre  leurs échanges. La passerelle fonctionne comme un proxy.

## Protocole de transmission 
L'envoi des données vers la plateforme thingspeak se fait en http avec une requête  GET.  Lorsque la ruche n'est pas directement connectée au réseau ethernet la requête est envoyée vers la passerelle sous la forme d'un ou plusieurs SMS suivant sa longueur. 
La requête http reçue  par la passerelle dans le ou les SMS est  réexpédiée tel-quel sur le réseau ethernet et la réponse obtenue  est renvoyée à l'expéditeur  qui en a fait la demande, également sous la forme de SMS. 
  
process transmission

Le processus thingspeakGET collecte les valeurs mesurées par les capteurs pour préparer la requête à envoyer à la plate-forme thingSpeak. Sa destination est   **https://api.thingspeak.com/update** 
```bash
pi@raspberrypi:~/Ruche/Capteurs $ ./thingSpeakGET BUNNFRUOOIJ4HM7X
https://api.thingspeak.com/update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
```
Cette requête est transmise sur l'entrée  de gammu-smsd-inject  qui la transmet  sous forme de SMS. La longueur de la requête étant de 183 caractères, 2 SMS seront nécessaires pour la transmettre.
Le pipe effectue cette connexion entre la sortie **1** de thingspeakGET (création de la requête) et l'entrée **0** de gammu-smsd-inject(envoi de SMS), comme l'illustre la figure ci-dessus.
```bash
*/30 * * * * /home/pi/Ruche/Capteurs/thingSpeakGET BUNNFRUOOIJ4HM7X | gammu-smsd-inject TEXT 0788887777 -len 183
```
Côté  gateway, lorsque les SMS sont reçus, le script SMSDreceive est exécuté pour reconstituer la requête en concaténant les SMS reçus : 
```bash
REQUETE=$SMS_1_TEXT$SMS_2_TEXT
```
puis la requête reconstituée  est transmise sur l'entrée standard du programme envoyerURL .
```bash
retour=`echo "$REQUETE" | /root/envoyerURL`
```
La réponse reçue du serveur thingspeak sera envoyée en retour à l'expéditeur.
```bash
echo $retour | gammu-smsd-inject TEXT $SMS_1_NUMBER -unicode
```
#### le script complet SMSDreceive côté Gateway:
```bash
#!/bin/sh
# script exécuter par le démon Gammu lors de la reception d'un SMS
# variables d'environnement
# SMS_1_CLASS
# SMS_1_NUMBER= numero tel
# SMS_1_TEXT= message
# SMS_MESSAGES = le nbre de SMS reçus
# en argument le fichier contenant le SMS

echo "---------------------------------------" >> /root/sms.log
echo "$(date) : $SMS_MESSAGES  SMS(s) recu(s)" >> /root/sms.log
echo "from : $SMS_1_NUMBER" >> /root/sms.log
REQUETE=$SMS_1_TEXT$SMS_2_TEXT
echo "message : $REQUETE" >> /root/sms.log

retour=`echo "$REQUETE" | /root/envoyerURL`
echo $retour >> /root/sms.log

echo $retour | gammu-smsd-inject TEXT $SMS_1_NUMBER -unicode

exit 0 
```
#### le script complet SMSDreceive côté Connected Beehive:
```bash
#!/bin/sh
# script exécuter par le démon Gammu lors de la reception d'un SMS
# variables d'environnement
# SMS_1_CLASS
# SMS_1_NUMBER= numero tel
# SMS_1_TEXT= message
# SMS_MESSAGES = le nbre de SMS reçus
# en argument le fichier contenant le SMS

DATE=`date '+%Y-%m-%d %H:%M:%S'`
echo "$DATE gsm $SMS_1_TEXT" >> /var/log/Ruche/activity.log
```

## Changelog

 **22/10/2018 :** Ajout du README . 

> **Notes :**

> - Licence : **licence publique générale** 
> - Auteur **Philippe SIMIER Lycée Touchard Le Mans**
>  
<!-- TOOLBOX 

Génération des badges : https://shields.io/
Génération de ce fichier : https://stackedit.io/editor#

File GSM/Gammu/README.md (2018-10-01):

# Envoyer et recevoir un SMS avec GAMMU

**Gammu** est un outil en ligne de commande qui permet la gestion de nombreux modem GSM.
Toutes les commandes de libGammu peuvent être utilisées en ligne de commande. 
**libGammu** est une bibliothèque exportant toutes les fonctionnalités de Gammu pour utilisation dans les programmes C. 
 Par la suite nous utiliseront le modem GSM **Quectel_M95** connecté via un  **click USB adapter** sur un port USB de la raspberry pi.

## Installer gammu

```bash
pi@PI1003:~ $ sudo apt install gammu
pi@PI1003:~ $ sudo apt-get install libgammu-dev
```

## Configurer gammu
Sur OS Linux, le fichier de configuration est recherché dans l'ordre suivant:

```bash
$XDG_CONFIG_HOME/gammu/config
~/.config/gammu/config
~/.gammurc
/etc/gammurc
```
Ce fichier utilise la syntaxe de fichier ini.

Vous pouvez utiliser **gammu-config** ou **gammu-detect** pour générer un fichier de configuration ou démarrer à partir d'un exemple entièrement documenté.

```bash
pi@PI1003:~ $ gammu-config
                                                                                
               ┌───────────────────────────────────────────────┐
               │ Current Gammu configuration                   │      
               │                                               │
               │  P Port                 (/dev/ttyUSB0)        │ 
               │  C Connection           (at115200)            │
               │  M Model                (at)                  │
               │  D Synchronize time     (yes)                 │ 
               │  F Log file             (/home/pi/gammu.log)  │ 
               │  O Log format           (textdate)            │
               │  L Use locking          ()                    │
               │  G Gammu localisation   ()                    │
               │  H Help                                       │
               │  S Save                                       │
               │                                               │
               │                                               │
               │          <Ok>              <Cancel>           │
               │                                               │
               └───────────────────────────────────────────────┘ 
```
les paramètres suivant doivent être renseignés, le Port  **/dev/ttyUSB0**
la vitesse de la transmission:  **at115200**
le modele: **at**      AT Generic phones
L'emplacement du fichier Log file  **/home/pi/gammu.log**
le format du log **textdate**

## Reconnaître le modem

A ce stade il est possible de vérifier si le modem est bien reconnu par gammu.
```bash
pi@PI1003:~ $ gammu identify

Device               : /dev/ttyUSB0
Manufacturer         : Quectel_Ltd
Model                : unknown (Quectel_M95)
Firmware             : M95AR01A21
IMEI                 : 863071014745126
SIM IMSI             : 208019006134389

```
Comme le montre l'écran ci-dessus nous obtenons différentes informations sur le constructeur, le modèle,  le firmware, le numero IMEI etc...

## Débloquer la carte SIM avec le code PIN

Pour envoyer ou recevoir des sms, la première chose à faire est de débloquer la carte SIM avec le code PIN requis. Ici, nous utilisons une carte SIM  avec le code pin est 0000.

```bash
pi@raspberrypi3:~ $ gammu entersecuritycode PIN 0000
```

Au bout de quelques secondes vous devriez voir la led rouge passer d'un clignotement rapide à un clignotement lent.

## Envoyer un SMS

```bash
pi@PI1003:~ $ gammu sendsms TEXT 0689744236 -text "gammu message"

If you want break, press Ctrl+C...
Sending SMS 1/1....waiting for network answer..OK, message reference=254

```
## Recevoir un SMS

Afin de voir vos sms reçus vous pouvez rentrer la commande suivante:

```bash
pi@raspberrypi3:~ $ gammu getallsms
Location 1, folder "Boîte de réception", SIM memory, Inbox folder
SMS message
SMSC number          : "+33689004000"
Envoyé              : sam. 29 sept. 2018 22:09:22  +0200
Coding               : Default GSM alphabet (no compression)
Remote number        : "+33689744236"
État                : UnRead

J'ai manqué votre appel.

1 SMS parts in 1 SMS sequences

```

[lien vers Jeedom](https://github.com/mbuffat/Jeedom-Gammu) 

--------

## Changelog

 **04/08/2018 :** Ajout du README . 
 **10/09/2018 :** Ajout du  script shell RaspbianOSsetup.sh
 
> **Notes :**

> - Licence : **licence publique générale** 
> - Auteur **Philippe SIMIER Lycée Touchard Le Mans**
>  
<!-- TOOLBOX 

Génération des badges : https://shields.io/
Génération de ce fichier : https://stackedit.io/editor#

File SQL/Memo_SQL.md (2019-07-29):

# Mémo SQL

## Connexion au serveur

La ligne de commande suivante permet de se connecter au serveur mysql en tant qu’utilisateur ruche (attention pas d'espace entre -p et le mot de passe).
```bash
mysql -u ruche -pxxxxxxxx72
Welcome to the MariaDB monitor.  Commands end with ; or \g.
Your MariaDB connection id is 98894
Server version: 10.1.26-MariaDB-0+deb9u1 Debian 9.1

Copyright (c) 2000, 2017, Oracle, MariaDB Corporation Ab and others.

Type 'help;' or '\h' for help. Type '\c' to clear the current input statement.

MariaDB [(none)]> show databases;
+--------------------+
| Database           |
+--------------------+
| data               |
| information_schema |
+--------------------+
2 rows in set (0.00 sec)

MariaDB [(none)]> use data;

```

## Ajouter une colonne 

Pour modifier la structure d'une table:  **ALTER**
La requète suivante ajoute une colonne status  **ADD `status`** de type enum à la table **things** après la colonne **name**.
```sql
 ALTER TABLE `things` ADD `status` ENUM('public','private') NULL DEFAULT NULL AFTER `name`;
```
## Mettre à jours la valeur d'un champ
Pour mettre à jour la valeur d'un champ : **UPDATE**
La requête suivante met à jours le champ **status** dans la table **things** pour la ligne dont l'**id** est égal à 1
```sql
UPDATE `data`.`things` SET `status` = 'public' WHERE `things`.`id` = 1;
```
## Créer une vue
Une vue est considérée comme une table virtuelle car elle n'a pas d’existence propre.
Une vue est créée à partir d'une requête de définition. 
```sql
CREATE
 ALGORITHM = UNDEFINED
 VIEW `users_things`
 AS SELECT `name`, `USER_API_Key`,`tag` FROM `things`,`users` where `user_id`=`users`.id
```
Interroger la vue `users_things`

Une fois créée une vue s’interroge comme une table. 
```sql
MariaDB [data]> SELECT * FROM `users_things`;
+----------------+------------------+----------+
| name           | USER_API_Key     | tag      |
+----------------+------------------+----------+
| Ruche France   | 9L0V9YXONAUJ0QRH | beehive  |
| Ruche Danemark | 9L0V9YXONAUJ0QRH | danemark |
| Ruche Philippe | RC8IK9LVVYEYZNSM | beehive  |
+----------------+------------------+----------+
3 rows in set (0.01 sec)

```

### Changelog

 **10/06/2019 :** Ajout de Authentification SSH par clés . 

> **Notes :**

> - Licence : **licence publique générale** 
> - Auteur **Philippe SIMIER Lycée Touchard Le Mans**
>  
<!-- TOOLBOX 

Génération des badges : https://shields.io/
Génération de ce fichier : https://stackedit.io/editor#
https://docplayer.fr/15188945-Le-traitement-d-images-avec-opencv.html

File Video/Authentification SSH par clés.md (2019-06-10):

# Authentification SSH par clés

## Introduction

L’authentification sur un serveur à l’aide d’une clé publique / privée a l'avantage de permettre de **se connecter au serveur sans utiliser de mot de passe**. Cela est indispensable si l'on souhaite copier un fichier avec scp sur le serveur à partir d'un script. 

## 1 Création des clés

Dans un premier temps, il est nécessaire en tant qu'utilisateur root de créer une clé publique privée sur sa machine en utilisant la commande **ssh-keygen** :
```bash
root@pi3PSR:/home/pi# cd ~
root@pi3PSR:~#  ssh-keygen -t rsa -b 2048
Generating public/private rsa key pair.
Enter file in which to save the key (/root/.ssh/id_rsa):[enter]
Created directory '/root/.ssh'.
Enter passphrase (empty for no passphrase):[enter]
Enter same passphrase again:[enter]
Your identification has been saved in /root/.ssh/id_rsa.
Your public key has been saved in /root/.ssh/id_rsa.pub.
The key fingerprint is:
SHA256:hQZDt5wN4dDRquFINWtskO53l3zAZ5ffLGiJbUWz6tA root@pi3PSR
The key's randomart image is:
+---[RSA 2048]----+
|     o=.=+       |
|    o oB.*.   o  |
|   . + oBoo  . + |
|    o *...o o =  |
|   o = oS. O * o.|
|    o + . * E . +|
|     . . . *   . |
|            .    |
|                 |
+----[SHA256]-----+
```
La commande demandera ou installer la clé privée, laissez l’emplacement par défaut à savoir  **/root/.ssh/id_rsa**
la commande va ensuite nous proposer de saisir une passphrase, entrer directement enter puis confirmer par enter.
Une fois créées, vous pourrez donc voir vos clés dans le répertoire "**.ssh**" de l'utilisateur root.

```bash
root@pi3PSR:~# ls -al .ssh
total 16
drwx------ 2 root root 4096 juin  10 16:33 .
drwx------ 8 root root 4096 juin  10 16:33 ..
-rw------- 1 root root 1679 juin  10 16:33 id_rsa
-rw-r--r-- 1 root root  393 juin  10 16:33 id_rsa.pub
```
Visualisation de la clé publique
```bash
root@pi3PSR:~# cd .ssh
root@pi3PSR:~/.ssh# more id_rsa.pub
ssh-rsa AAAAB3NzaC1yc2EAAAADAQABAAABAQC5p7K7SdizMG9OgMZg777jy87V9jkQnnbFZDPwP1Fw
/zEWZ2xd7sMOOoU8IVHoIk9Pm2LqOGQSVNgQj8FqDz5TWF3Nb+ucFoZIkPt+0T/G4YfLTbdHp69bJU4n
Uzhx6qGlhNryS7wPKNyQyC4pqeKr6tzNBUbPYRA1bL2ONhf16nqY/8Ah9H/Kcyo6bIkZPCjU7kaZFa/z
d1PV11GOzgb2WBD2FPt/AidZIBsV1clrfhYBhC5RbOTXq9eYGA4s9/bOmGdJ9rz0B6HIq3XIOAhoDEWq
aRxFJZTctxUTlONE0otnaRtflAsiRoWucmTR67Tn65CEebFHEaSEqdt4XrfT  root@pi3PSR 
```
## Copie de la clé publique sur le serveur
Afin de pouvoir utiliser cette clé pour s’authentifier au serveur souhaité, il est nécessaire de la copier dans les clés autorisées du compte utilisateur root sur le serveur.
Pour ce faire :
```bash
root@pi3PSR:~# cat ~/.ssh/id_rsa.pub | ssh root@172.18.58.9 "cat - >> ~/.ssh/authorized_keys"
password:
```
NB2 : Il est à noter que les clés sont valables pour une machine et un utilisateur particulier.

## Tests
Vérification de la clé sur le serveur
```bash
root@dmz:~/.ssh# more authorized_keys
```
Maintenant que notre clé publique est présente sur le serveur et que nous possédons dans notre répertoire .ssh sa clé privée associée, nous allons pouvoir nous connecter au serveur juste en saisissant la commande suivante :

Connexion sur 172.18.58.9 en tant que root à partir de pi3PSR
```bash
root@pi3PSR:~#  ssh -i /root/.ssh/id_rsa 172.18.58.9
```
Copie d'un fichier :
```bash
root@pi3PSR:~# scp /var/tmp/ram_drive/cam.jpg root@172.18.58.9:/var/www/Ruche/video
```
### Changelog

 **10/06/2019 :** Ajout de Authentification SSH par clés . 

> **Notes :**

> - Licence : **licence publique générale** 
> - Auteur **Philippe SIMIER Lycée Touchard Le Mans**
>  
<!-- TOOLBOX 

Génération des badges : https://shields.io/
Génération de ce fichier : https://stackedit.io/editor#
https://docplayer.fr/15188945-Le-traitement-d-images-avec-opencv.html

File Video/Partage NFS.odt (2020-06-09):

# partage NFS

NFS permet à un système de partager des répertoires et des fichiers à travers un réseau. En utilisant NFS, les programmes peuvent accéder aux fichiers de systèmes distants comme s'ils étaient des fichiers locaux.

### Configuration du serveur

Sur le serveur DMZ serveur NFS

les dossiers partagés (à exporter) sont définis dans /etc/exports

# /etc/exports: the access control list for filesystems which may be exported

# to NFS clients. See exports(5).

# Example for NFSv2 and NFSv3:

# /srv/homes hostname1(rw,sync,no_subtree_check) hostname2(ro,sync,no_subtree_check)

# Example for NFSv4:

# /srv/nfs4 gss/krb5i(rw,sync,fsid=0,crossmnt,no_subtree_check)

# /srv/nfs4/homes gss/krb5i(rw,sync,no_subtree_check)

/var/www/Ruche/video 172.18.58.253(rw,fsid=0,sync,no_root_squash,no_subtree_check)

### Configuration du client

Le client NFS est sur la raspberry webcam

Utiliser la commande mount pour monter à la main un répertoire NFS partagé à partir d'une autre machine, en tapant dans un terminal la commande suivante :

root@webcam:/home/pi/video# mount -t nfs4 172.18.58.9:/ video

Le répertoire /home/pi/video/video du point de montage doit exister.

### Montage automatique FSTAB

Il est également possible de monter automatiquement les répertoires partagés au démarrage de l'ordinateur client. Pour ce faire on va rajouter une ligne dans le fichier /etc/fstab.

La ligne doit comporter le nom d'hôte du serveur NFS,
le répertoire du serveur qui doit être partagé,
et le répertoire de la machine locale où le partage NFS doit être monté.

proc /proc proc defaults 0 0

PARTUUID=f0fb3126-01 /boot vfat defaults 0 2

PARTUUID=f0fb3126-02 / ext4 defaults,noatime 0 1

tmpfs /var/tmp/ram_drive tmpfs nodev,nosuid,size=10M 0 0

# a swapfile is not a swap partition, no line here

# use dphys-swapfile swap[on|off] for that

172.18.58.9:/var/www/Ruche/video /home/pi/video/video nfs4 defaults 0 0

Pour ne pas redémarrer et avoir accès pour la première fois au dossier partagé on peut utiliser mount comme suit :

mount -a

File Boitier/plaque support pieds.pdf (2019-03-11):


Alu 40 x 5

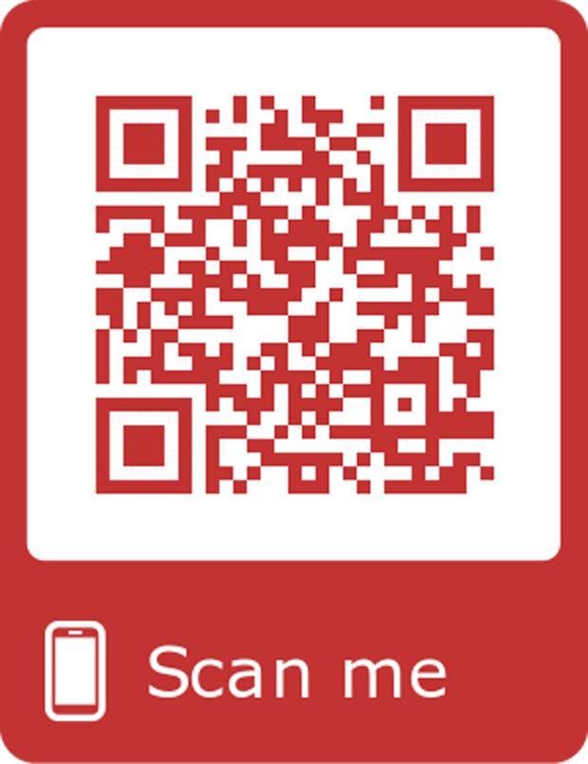
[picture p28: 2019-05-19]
html/images/QR connected.png

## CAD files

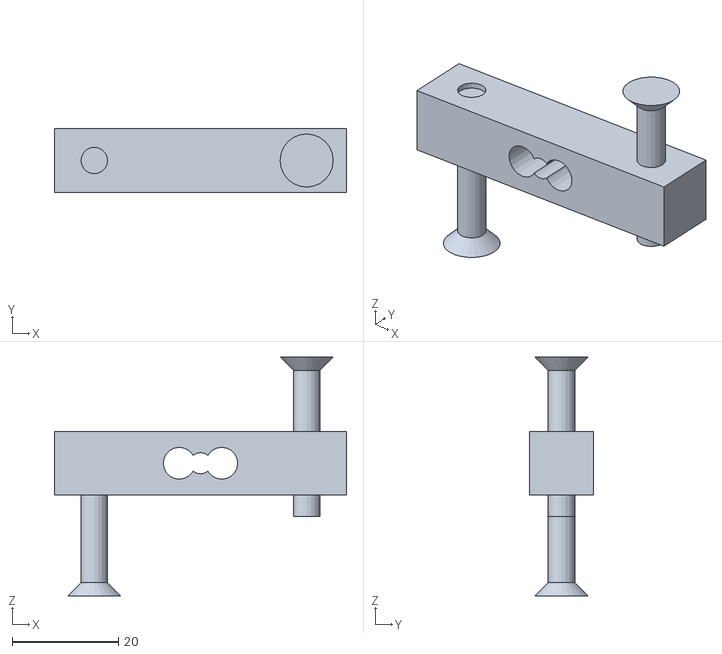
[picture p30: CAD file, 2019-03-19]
Boitier/assemblage capteur force.stl
55.0 x 12.0 x 45.0

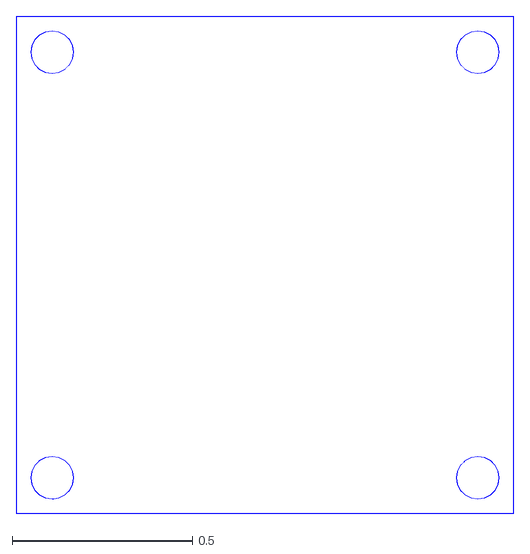
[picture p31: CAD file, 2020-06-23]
Boitier/couvercle capteur.dxf
1.38 x 1.38

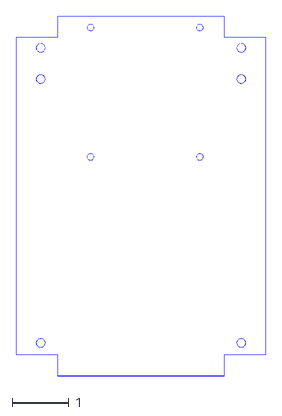
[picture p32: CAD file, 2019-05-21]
Boitier/plaque support.dxf
4.40 x 6.36

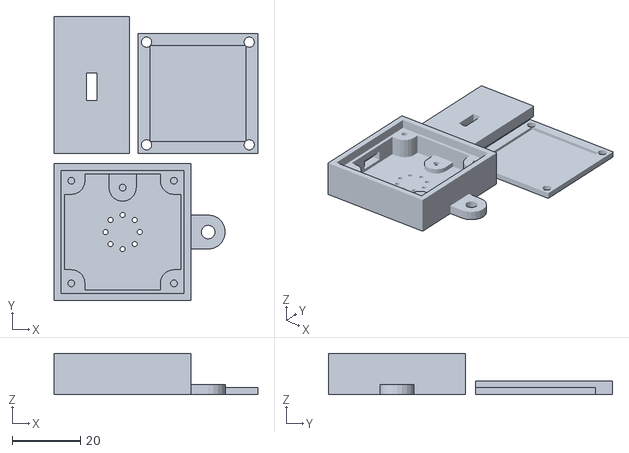
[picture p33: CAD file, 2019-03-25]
Boitier/Boitier BME280.stl
59.5 x 83.0 x 12.0

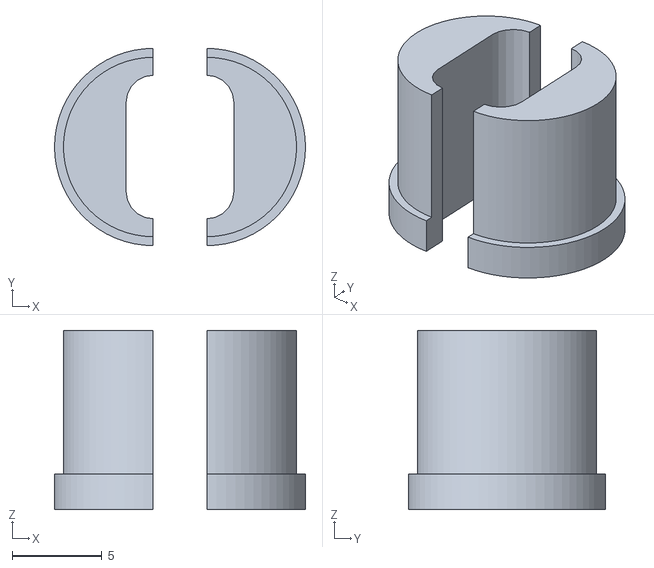
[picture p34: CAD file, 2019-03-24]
Boitier/joint fil plat.stl
14.0 x 11.0 x 10.0

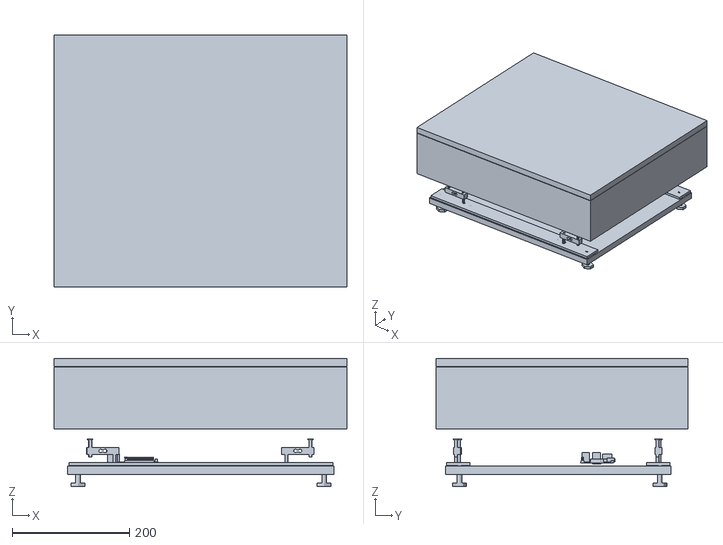
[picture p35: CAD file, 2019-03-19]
Boitier/Boitier Balance Ruche.stl
500.0 x 430.0 x 219.0

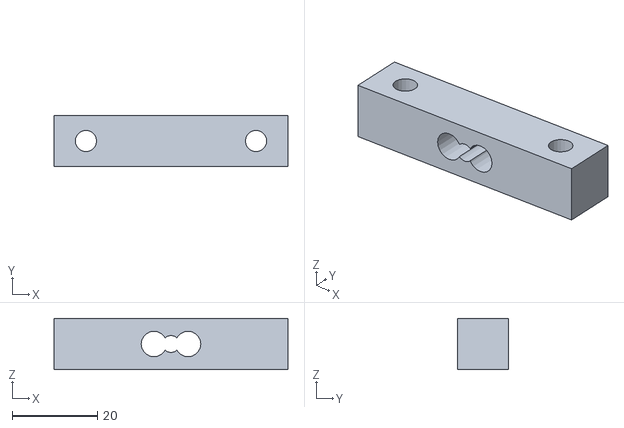
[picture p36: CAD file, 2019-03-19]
Boitier/capteur force.stl
55.0 x 12.0 x 12.0

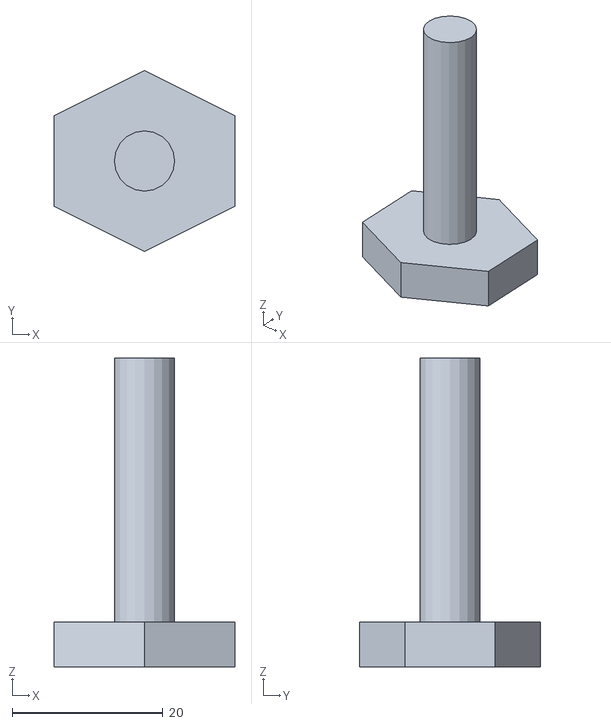
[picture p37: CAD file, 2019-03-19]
Boitier/Verrin.stl
24.0 x 24.0 x 41.0

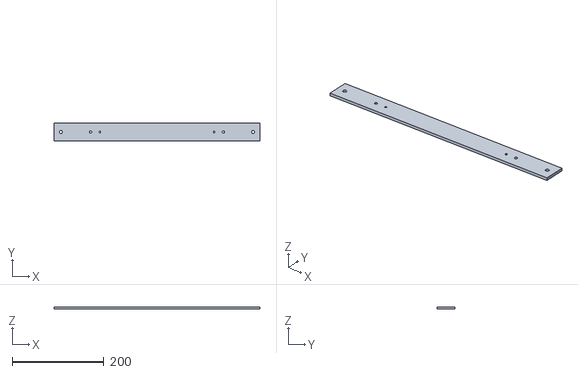
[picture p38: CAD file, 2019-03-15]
Boitier/Fixation capteurs.stl
450.0 x 40.0 x 5.00

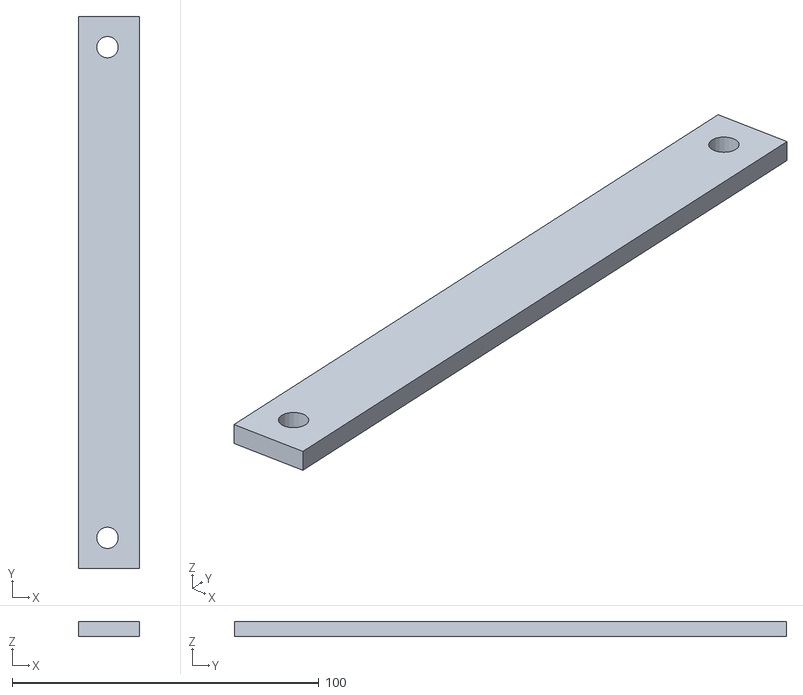
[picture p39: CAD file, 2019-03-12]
Boitier/fixation batterie.stl
20.0 x 180.0 x 5.00

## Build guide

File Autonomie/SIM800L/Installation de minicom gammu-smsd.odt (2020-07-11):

Gsm SIM800L

# Installation de la liaison série ttyS0

Dans raspi-config choisir

5 Interfacing-Options

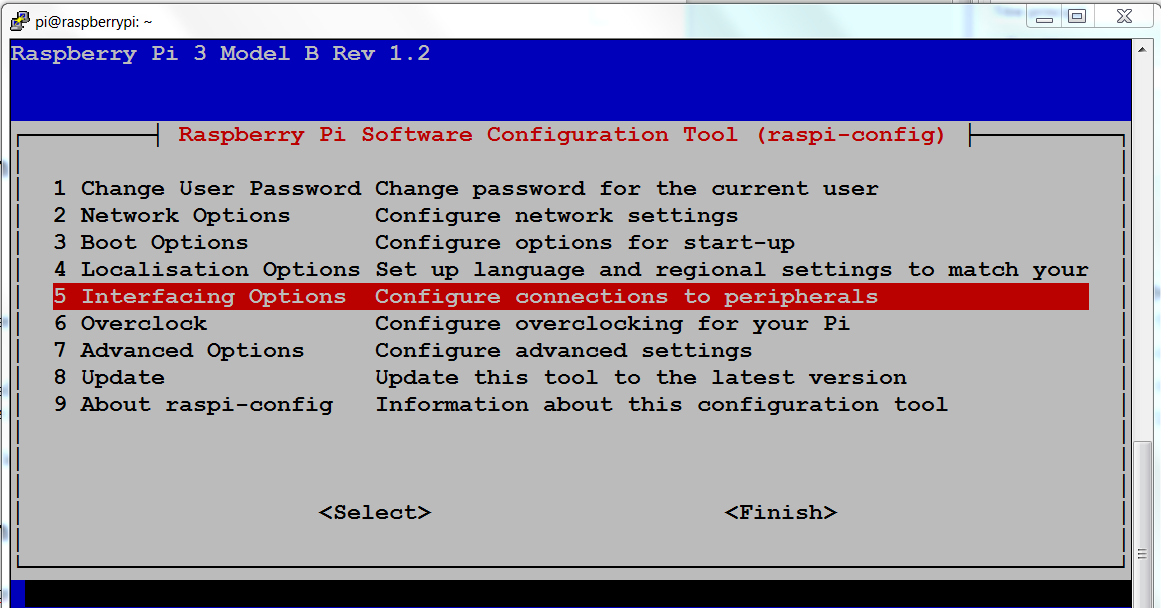
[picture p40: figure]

puis choisir P6-serial

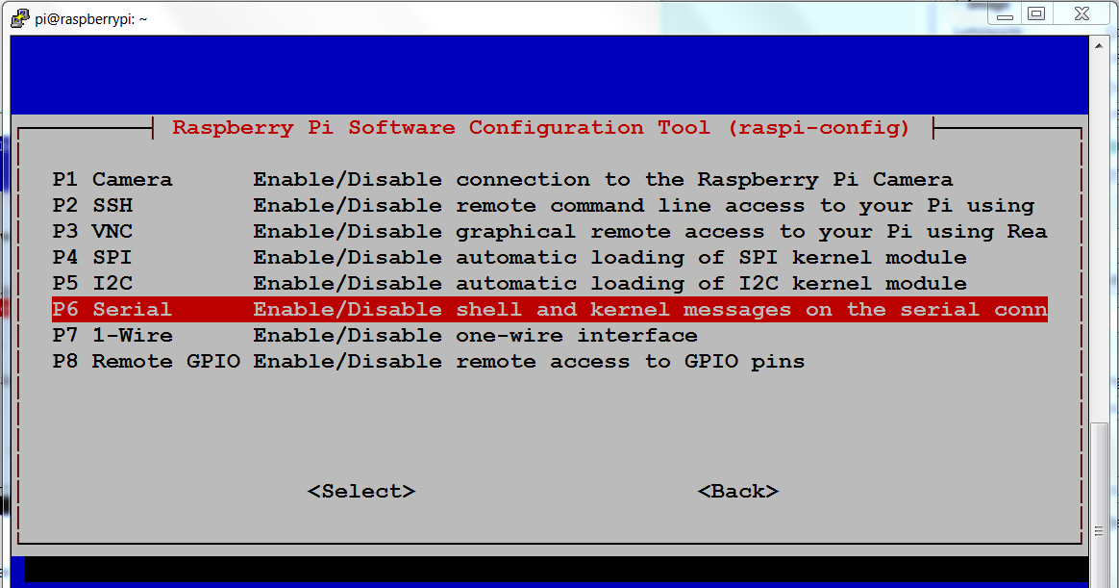
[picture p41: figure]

désactiver le shell et activer le port série

Valider la fenêtre

The serial login shell is disabled

The serial interface is enabled

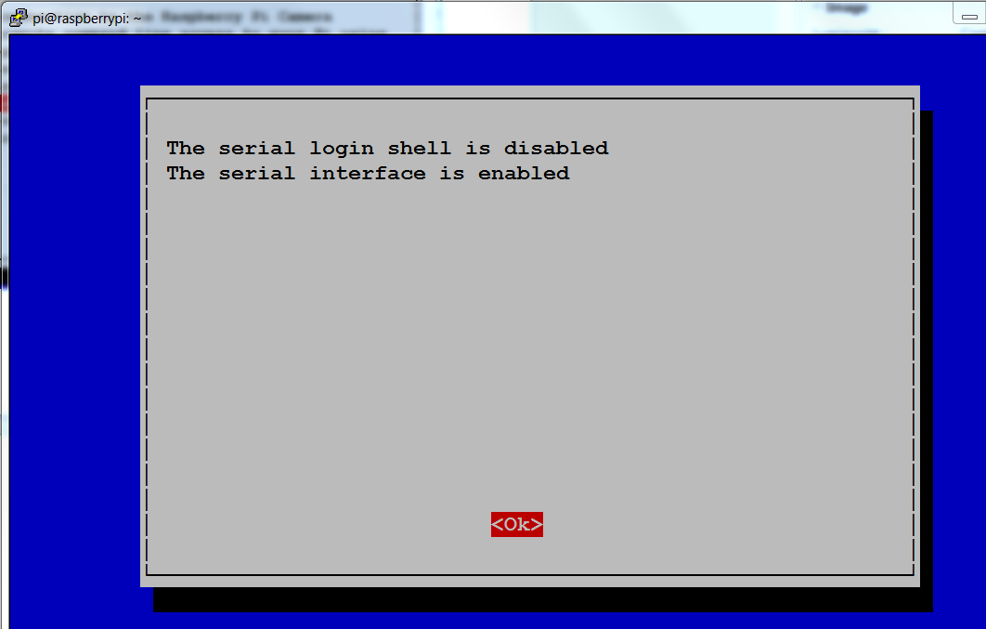
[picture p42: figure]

puis rebouter pour valider les options.

# Installation de minicom

root@raspberrypi:/dev# apt install minicom

exécuter minicom

root@raspberrypi:/dev# minicom -s

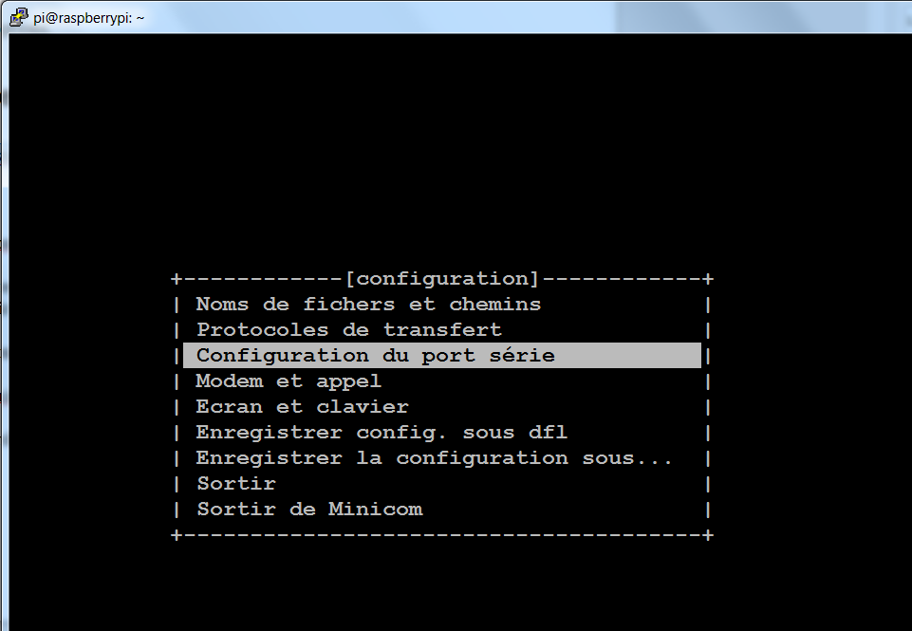
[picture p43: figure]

régler le port série sur ttyS0 vitesse 115200 8N1

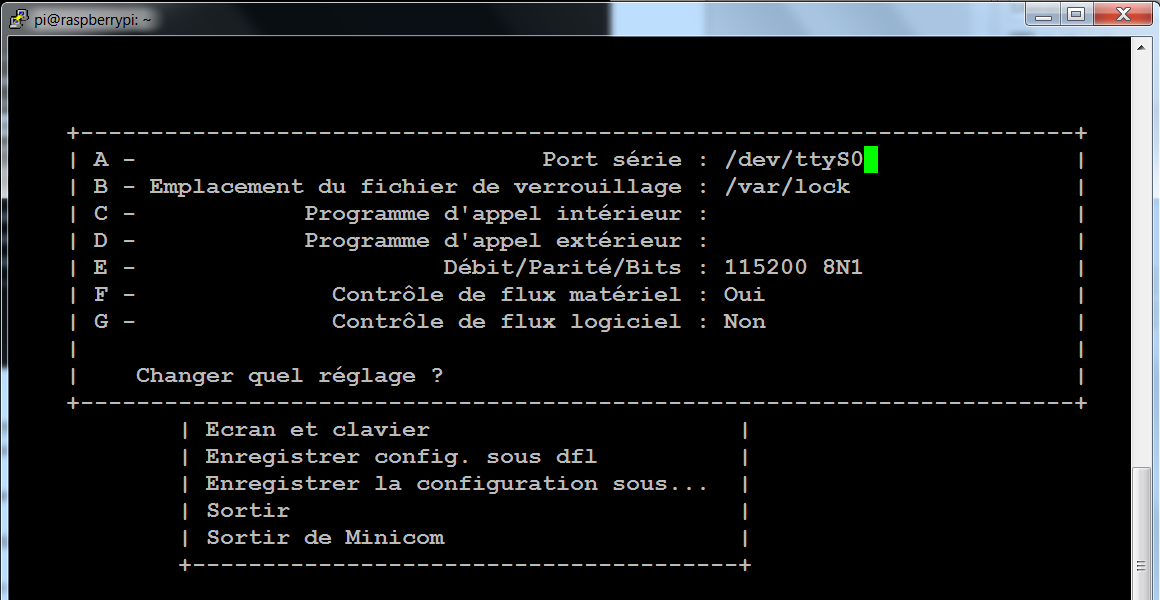
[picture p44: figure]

enregistrer la config puis choisir sortir.

Saisir la commande at le modem doit répondre OK

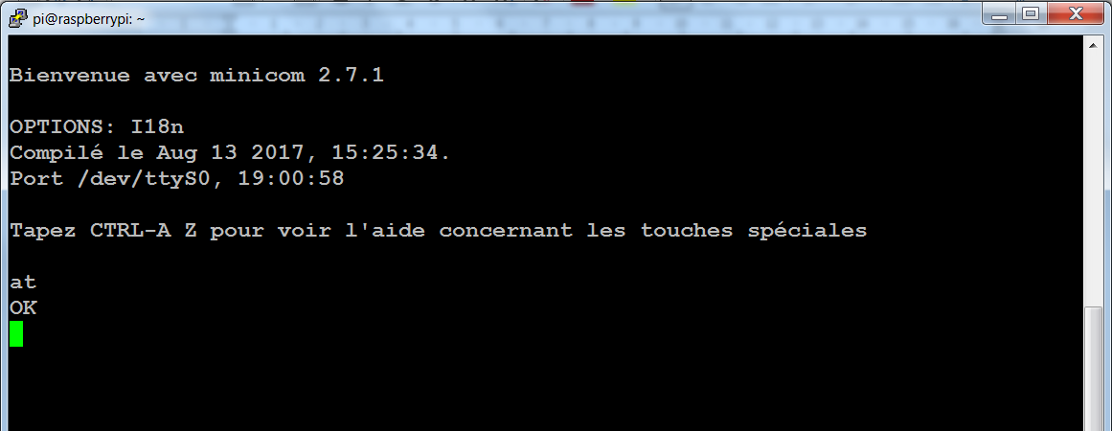
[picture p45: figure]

contrôle A Z Q pour sortir de minicom.

A partir de cette étape le raccordement du modem SIM800L est validé

# Installation de gammu-smsd

Le modem Sim800L est compatible avec le daemon gammu-smsd.

root@raspberrypi:/dev# apt install gammu-smsd

root@raspberrypi:/dev# gammu-smsd -v

Gammu-smsd version 1.40.0

# Configuration de gammu-smsd

gammu-smsd lit la configuration à partir d'un fichier de configuration. Son emplacement peut être spécifié sur la ligne de commande (option -c), sinon le fichier par défaut /etc/gammu-smsdrc est utilisé.

# Configuration file for Gammu SMS Daemon

[gammu]

port = /dev/ttyS0

connection = at

[smsd]

service = files

logfile = syslog

# Increase for debugging information

debuglevel = 0

pin = 0000

# Paths where messages are stored

inboxpath = /var/spool/gammu/inbox/

outboxpath = /var/spool/gammu/outbox/

sentsmspath = /var/spool/gammu/sent/

errorsmspath = /var/spool/gammu/error/

Arrêter le deamon puis redémarrer

root@raspberrypi:/dev# sudo service gammu-smsd stop

root@raspberrypi:/dev# sudo service gammu-smsd start

# Installation du reset

Installer WiringPi

apt install wiringpi

Copier le fichier resetGSM.c dans home/pi

le compiler

installer dans le crontab la ligne suivante

@reboot /home/pi/resetGSM

# Envoyer un SMS

La commande gammu-smsd-inject permet de créer et d’envoyer un SMS.

root@raspberrypi:/home/pi# gammu-smsd-inject TEXT 0689744235 -text "Nous sommes le `date`"

gammu-smsd-inject[861]: Created outbox message OUTC20200503_172007_00_0689744235 _sms0.smsbackup

Written message with ID /var/spool/gammu/outbox/OUTC20200503_172007_00_068974423 5_sms0.smsbackup

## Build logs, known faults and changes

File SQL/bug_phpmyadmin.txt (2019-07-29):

le message d'erreur est

Warning in ./libraries/sql.lib.php#601
count(): Parameter must be an array or an object that implements Countable

et la solution est là : https://stackoverflow.com/a/49483740/3175946

remplacer

(count($analyzed_sql_results['select_expr'] == 1)
par

(count($analyzed_sql_results['select_expr']) == 1

dans /usr/share/phpmyadmin/libraries/sql.lib.php (ligne 613)

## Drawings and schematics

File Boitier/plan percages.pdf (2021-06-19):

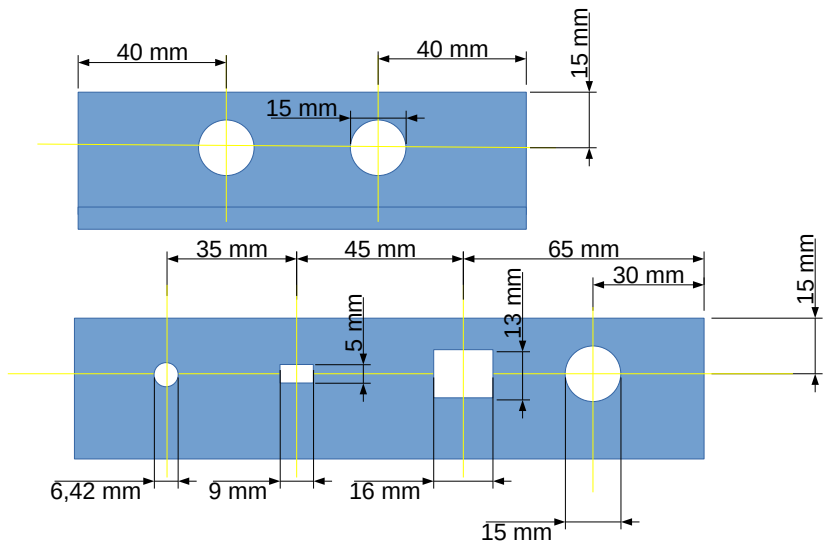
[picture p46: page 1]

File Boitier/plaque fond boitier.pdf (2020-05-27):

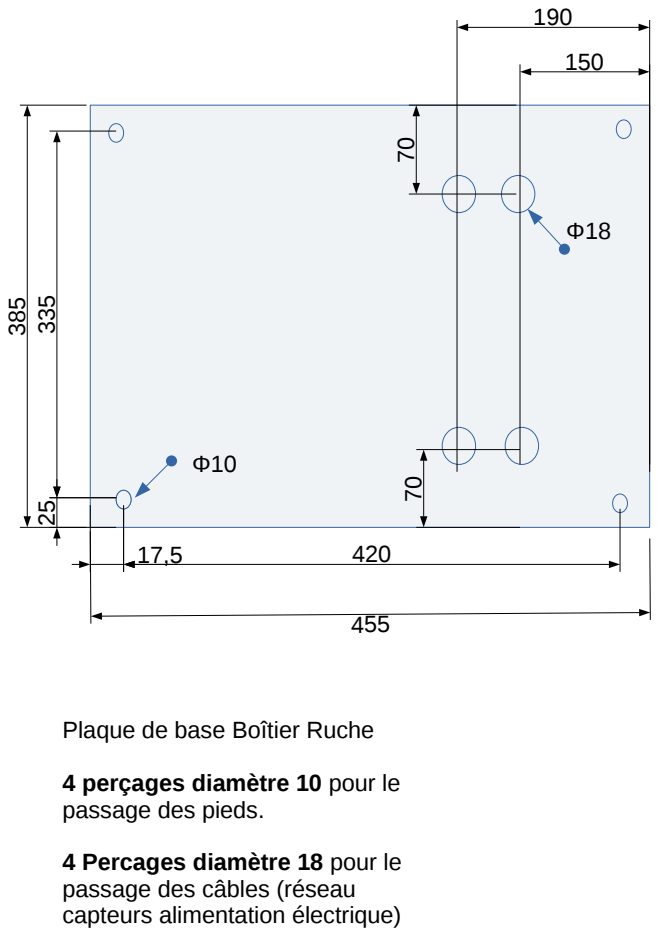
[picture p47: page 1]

Plaque de base Boîtier Ruche

4 perçages diamètre 10 pour le
passage des pieds.

4 Percages diamètre 18 pour le
passage des câbles (réseau
capteurs alimentation électrique)

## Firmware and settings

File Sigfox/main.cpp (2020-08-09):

/*

    @date     18 Juillet 2020
    @version  v1.0 - first release
    @detail   Programme test unitaire classe Sigfox
              Compilation  : g++  main.cpp sigfox.cpp serie.c -o main
              Execution    : ./main


*/

#include <iostream>
#include <string>
#include "sigfox.h"

typedef struct {
    short field1;
    short field2;
    short field3;
    short field5;
    short field6;
    unsigned char  field4;
    unsigned char  type;
} trame;

using namespace std;

int main(void)
{

    trame t;
    Sigfox device("/dev/ttyS0", true);

    // test du fct composant
    cout << "test : " << device.tester() << endl;
    // Affichage de l'identifiant
    cout << "Sigfox ID : " << device.obtenirID() << endl;
    // Affichage du PAC number
    cout << "PAC : " << device.obtenirPAC() << endl;

    t.field1 = 12501;
    t.field2 = 5011;
    t.field3 = 10249;
    t.field4 = 64;
    t.field5 = 48214;
    t.field6 = 2031;
    t.type   = 3;

    cout << device.envoyer((void*)&t,12) << endl;

    return 0;
}

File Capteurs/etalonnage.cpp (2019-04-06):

/**
 *  @file     etalonnage.cpp
 *  @author   Philippe SIMIER (Touchard Wahington le Mans)
 *  @license  BSD (see license.txt)
 *  @date     6 juin 2018
 *  @brief    programme étalonnage de la balance
 *            ce programme détermine les constantes offset scale et gain et
 *            les enregistre dans le fichier configuration.ini
 *            compilation: g++ etalonnage.cpp hx711.cpp SimpleIni.cpp  spi.c -o etalonnage
*/

#include <iostream>
#include <fstream>
#include <iomanip>
#include "hx711.h"
#include "SimpleIni.h"

#define CONFIGURATION "/opt/Ruche/etc/configuration.ini"

using namespace std;

int main()
{

    hx711 balance;
    SimpleIni ini;

    int x1,x2;
    int offset;
    float scale;
    int gain;
    float poids;
    string unite;
    int precision;

    if(!ini.Load(CONFIGURATION))
    {
        cout << "Impossible d'ouvrir le fichier configuration.ini !!" << endl;
        return -1;
    }

    cout << "Quelle est l'unité de mesure ? (g kg lb)" << endl;
    cin >> unite;
    ini.SetValue<string>("balance", "unite", unite);

    do
    {
        cout << "Quelle est la précision d'affichage : 1 ou 2 chiffres après la virgule" << endl;
        cin >> precision;
    }
    while (precision !=1 && precision !=2);
    ini.SetValue<int>("balance", "precision", precision);

    do
    {
        cout << "Donnez le gain souhaité : 128 ou 64 ? " << endl;
        cin >> gain;
    }
    while (gain !=128 && gain !=64);
    ini.SetValue<int>("balance", "gain", gain);

    balance.configurerGain(gain);
    int max,min,som;
    som = balance.obtenirValeur();
    min = som;
    max = som;
    for(int i=1 ; i<100 ; i++)
    {
        x1 = balance.obtenirValeur();
        cout << x1 << endl;
        som += x1;
        if (x1 > max) max = x1;
        if (x1 < min) min = x1;
    }
    offset = (som - max - min)/ 98;
    cout << "offset : " << offset << endl;
    ini.SetValue<int>("balance", "offset", offset);

    cout << "Posez un poids étalon sur le plateau et donnez sa valeur en " << unite << " : " << endl;
    cin >> poids;
    cout << "Vous avez posé un poids de " << poids << " " << unite << endl;

    som = balance.obtenirValeur();
    max = som;
    min = som;
    for(int i=1 ; i<100 ; i++)
    {
        x2 = balance.obtenirValeur();
        cout << x2 << endl;
        som += x2;
        if (x2 > max) max = x2;
        if (x2 < min) min = x2;

    }
    x2 = (som - max - min)/98 ;
    scale = (float)(x2 - offset)/poids;
    cout << "scale : " << scale  << endl;
    ini.SetValue<float>("balance", "scale", scale);


    if(!ini.SaveAs(CONFIGURATION))
    {
        cout << "Impossible d'écrire dans configuration.ini." << endl;
        return -1;
    }

    cout << "Le fichier de configuration : configuration.ini a été enregistré." << endl;

    return 0;

}

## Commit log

2018-09-06 add methode poids corrigé en fct de la temp
    [hx711.cpp, main.cpp]
2018-09-15 update script création de base data
2018-09-17 add scatter plot temperature humidity
2019-03-12 add fichier stl
    [fixation batterie.stl]
2019-03-15 add Fixation capteurs de force
    [Fixation capteurs.stl]
2019-03-15 add boitier.stl
    [Boitier Balance Ruche.stl]
2019-03-19 add capteurs de force
2019-03-19 add pièces mécaniques
    [Boitier BME280.stl, Boitier Balance Ruche.stl, Verrin.stl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]
2019-03-24 add joint fil plat
    [joint fil plat.stl]
2019-03-24 add plaque support raspberry
    [plaque support.dxf]
2019-03-25 update support BME & plaque
    [Boitier BME280.stl, plaque support.dxf]
2019-04-06 add battery
2019-04-19 add battery.php
2019-04-25 update battery SOC
2019-04-27 update calcul du taux de charge
2019-05-03 add test Battery
2019-05-19 update menu
    [config_apache.txt]
2019-05-21 add Thing Speak
    [plaque support.dxf]
2019-06-20 add gestion des axes Y améliorée
2020-06-05 update battery
2020-06-10 update intégration méthode des trapezes
2020-06-23 add couvercle capteur
    [couvercle capteur.dxf]
2020-07-08 update hx711.cpp poids > 95kg
2020-07-11 update charge=capacite
2020-07-12 add RSSI
    [RSSI.ods]
2020-07-26 add batterySigfox
2020-08-04 add deviceSigfox
